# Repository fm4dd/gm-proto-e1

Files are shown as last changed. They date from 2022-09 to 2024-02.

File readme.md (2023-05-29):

## GM-PROTO-E1

### Description

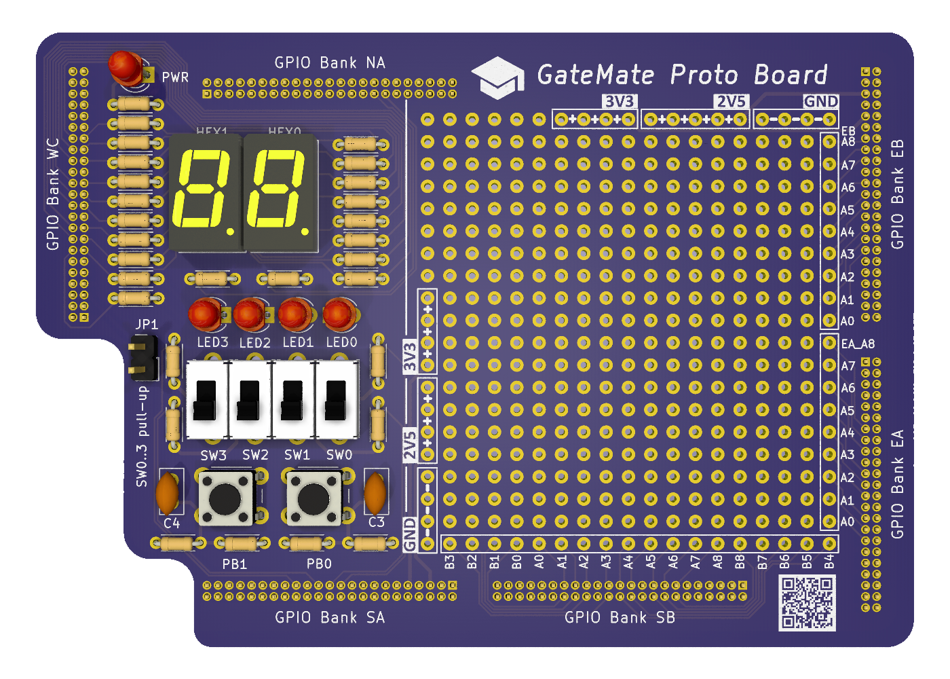
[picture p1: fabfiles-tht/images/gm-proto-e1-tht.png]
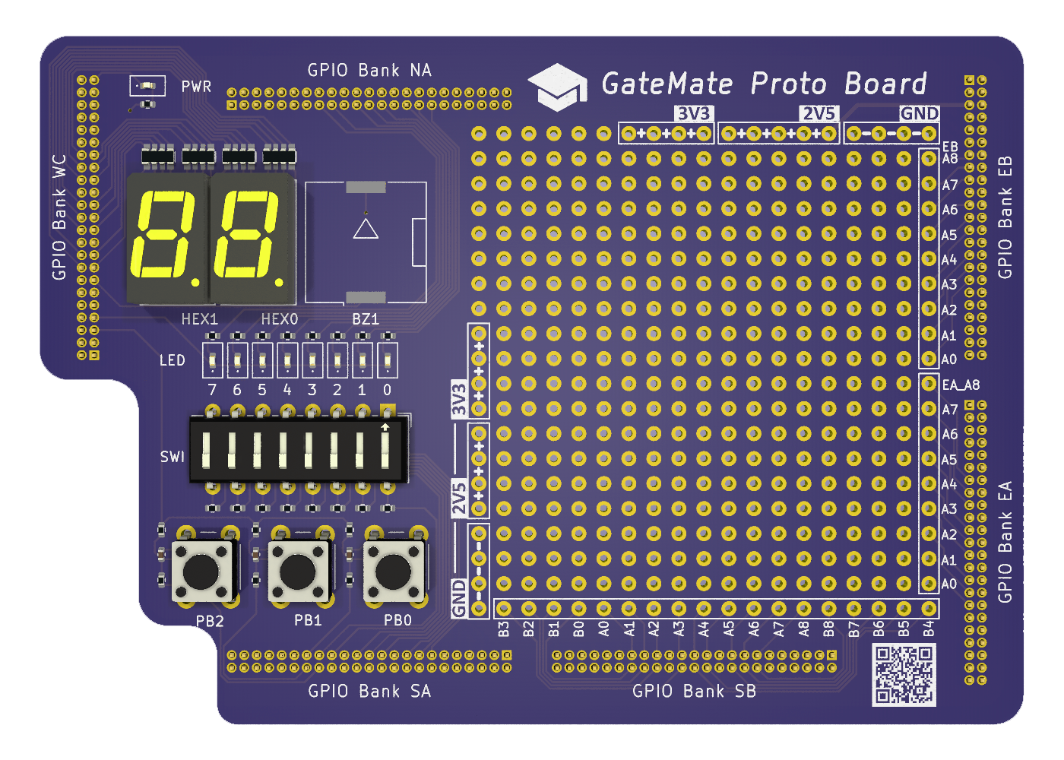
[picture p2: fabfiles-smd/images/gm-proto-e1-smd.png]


The gm-proto-e1 board is an application module board for the <a href="https://www.colognechip.com/programmable-logic/gatemate-evaluation-board/">GateMate FPGA evaluation board E1</a>, made by <a href="https://www.colognechip.com/">Cologne Chip</a>. It connects to the evaluation board through the GPIO bank headers, and its main feature is the 20x19 standard 2.54mm pitch prototyping area. 36 FPGA signals from GPIO banks SB, EA and EB are brought in to enable easy experimentation for connecting FPGA board peripherals. In addition, the application board provides a minimal set of data input/output components for basic FPGA interactions. Two variants have been designed: One for through-hole components, one for higher density SMD parts:

- 2x push buttons THT / 3x push buttons SMD
- 4x slide switches THT / 8x DIP switches SMD
- 4x LED THT / 8x LED SMD
- 2x 7-Segment display modules
- Buzzer (SMD only)

This design is registered under the OSHWA Open Source Hardware Self-Certification:  


### Hardware Versions

The gm-proto-e1 application board has been designed as a 100x70mm double-layer PCB, with precision alignment of the six 46-pin 1.27mm pitch GPIO connectors, verified to fit the GateMate FPGA evaluation board E1 V3.1B. For THT components, great care needs to be taken to cut pins flush during soldering and prevent them from reaching components of the evaluation board below. The 1.27mm pitch GPIO connectors are offered with different distance spacers (2, 2.5 and 5mm), and the standard spacers achieve only 5mm total clearance.

#### Through-hole Design:

| Version | Gerber | Schema |
|---|---|---|
| 1.0 |[20220914-gm-proto-e1-gerber.zip](fabfiles-tht/v10/20220914-gm-proto-e1-gerber.zip) | [20220914-gm-proto-e1-schematic.pdf](fabfiles-tht/v10/20220914-gm-proto-e1-schematic.pdf) |

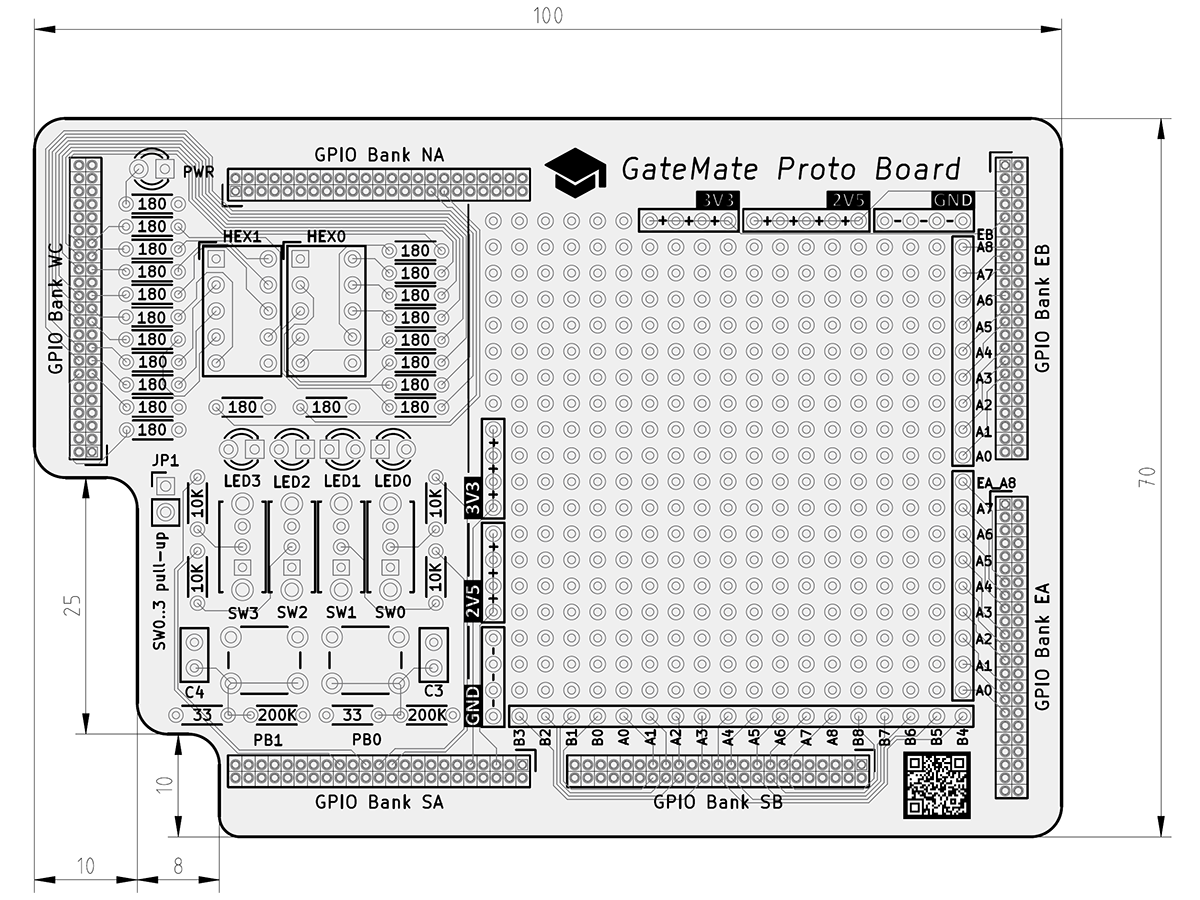
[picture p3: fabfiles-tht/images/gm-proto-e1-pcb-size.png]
 
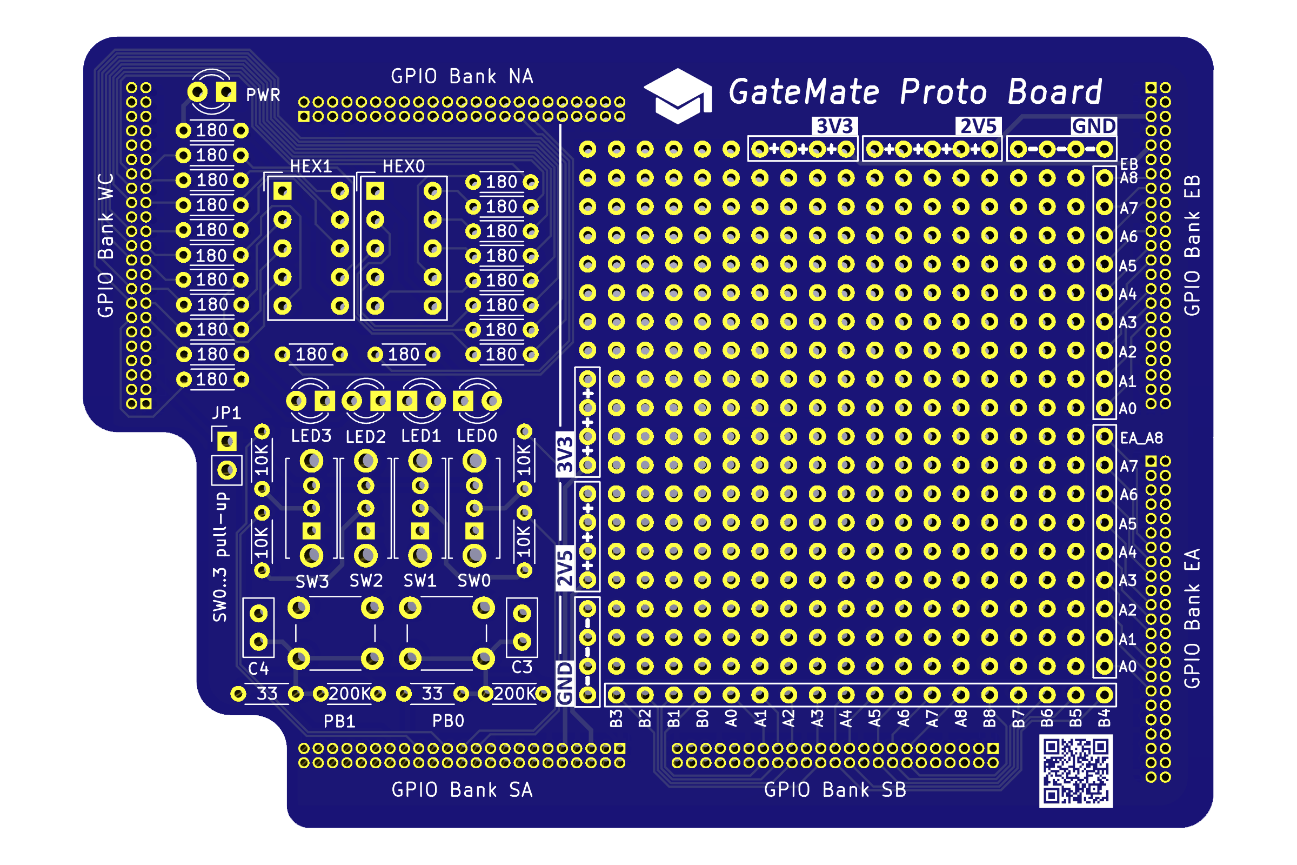
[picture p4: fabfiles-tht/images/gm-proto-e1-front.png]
 

#### Surface-Mount Design:

| Version | Gerber | Schema |
|---|---|---|
| 1.0 |[20220923-gm-proto-e1-gerber.zip](fabfiles-smd/v10/20220923-gm-proto-e1-gerber.zip) | [20220923-gm-proto-e1-schematic.pdf](fabfiles-smd/v10/20220923-gm-proto-e1-schematic.pdf) |

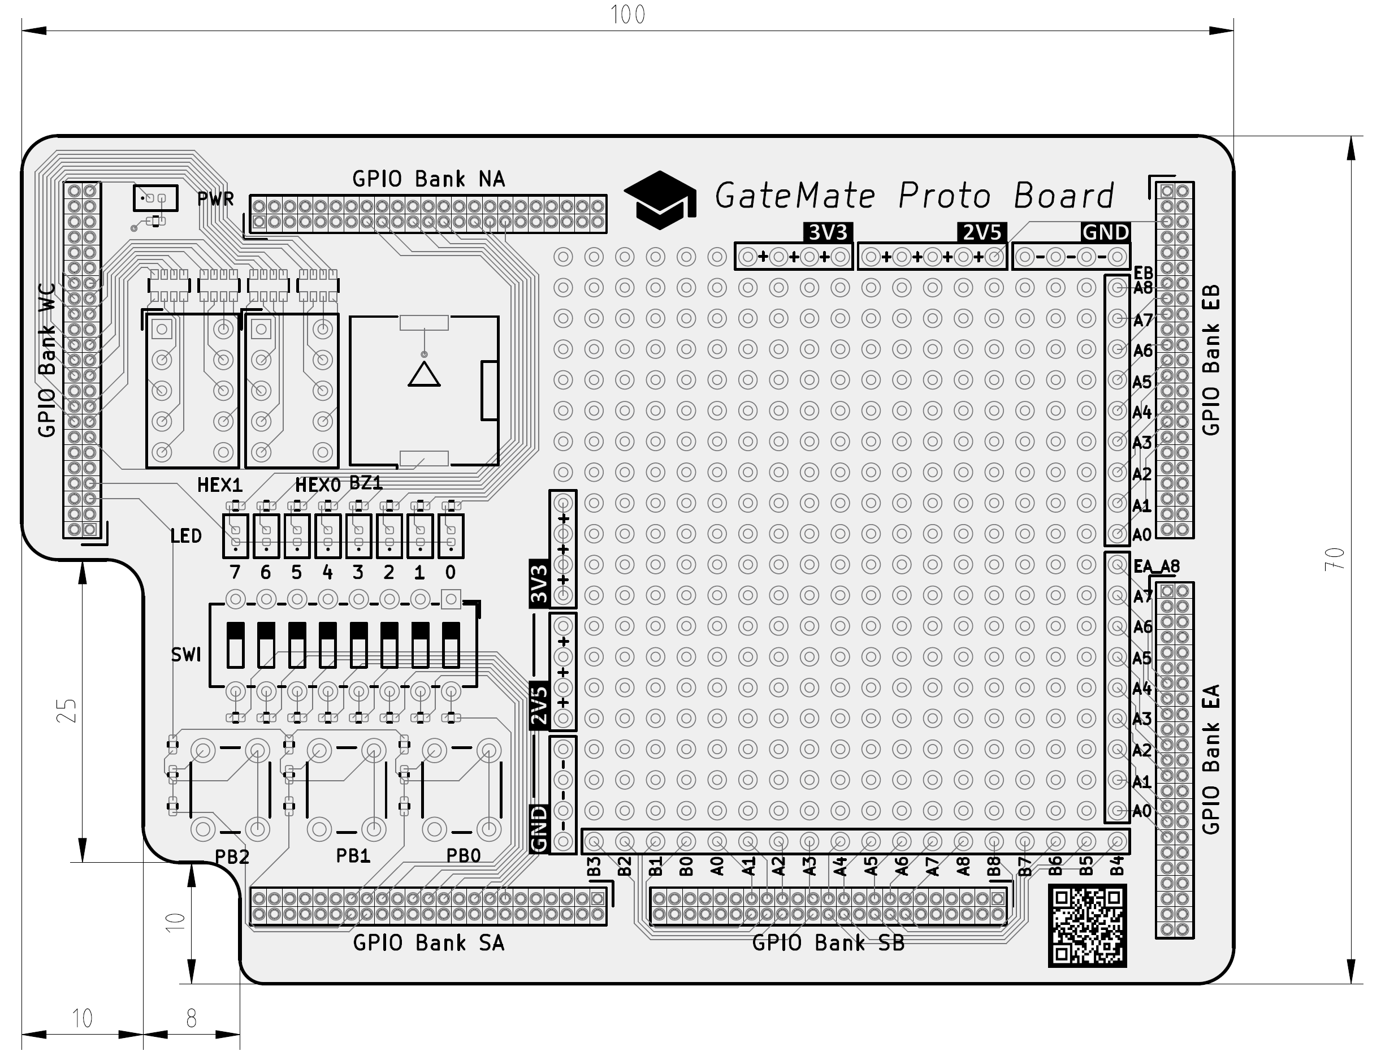
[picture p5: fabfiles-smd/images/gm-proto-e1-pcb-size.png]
 
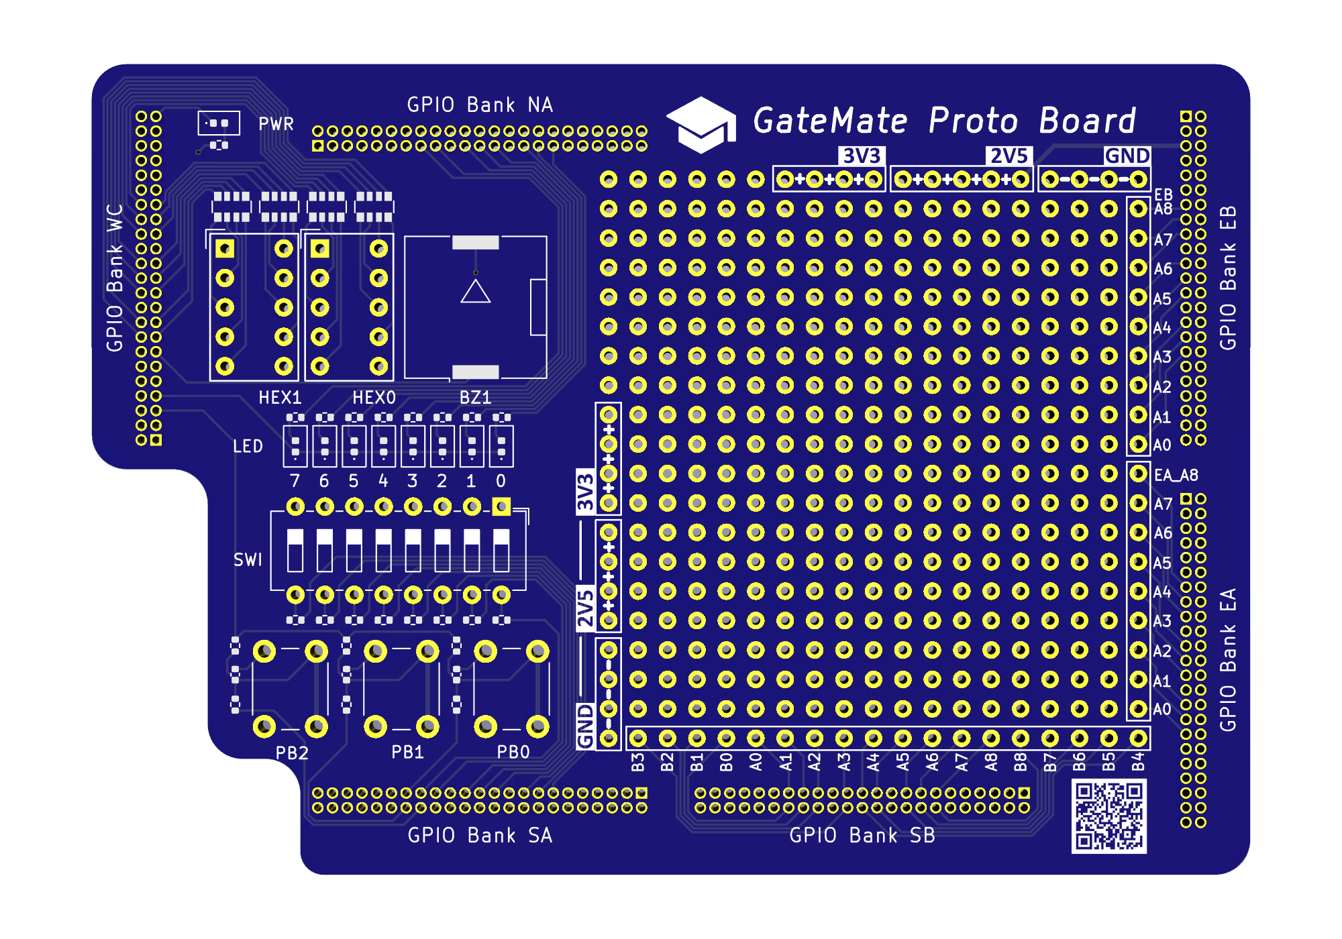
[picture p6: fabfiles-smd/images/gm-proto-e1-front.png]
 

### Pin Assignments

Due to IO differences between THT and SMD board variants, they have different pinouts:

#### Through-hole Design:

- IO pinout assigments file: [pin-assignment-tht.md](pin-assignment-tht.md)
- hardware constraints file: [gm-proto-e1-tht.ccf](examples-tht/gm-proto-e1-tht.ccf)

#### Surface-Mount Design:

- IO pinout assigments file: [pin-assignment-smd.md](pin-assignment-smd.md)
- hardware constraints file: [gm-proto-e1-smd.ccf](examples-smd/gm-proto-e10-smd.ccf)

Note: Components are prefixed with "pr", to identify them belonging to the gm-proto-e1 application board. For prototyping, 36 IO signals from GPIO banks SB, EA and EB have been placed into the 2.54mm area border pin rows.

### Example Code

The following code examples demonstrate the board input/output components for quick verification. The code has been tested with the pre-compiled opensource toolchain released through the GateMate support site at <a href="https://www.colognechip.com/mygatemate/">https://www.colognechip.com/mygatemate/</a>

#### Through-hole Design:

| Language | Folder | Description |
|---|---|---|
| Verilog  |[blink](examples-tht/blink) | blinks two LED's in a alternating pattern |
| Verilog  |[count](examples-tht/count) | binary counter displayed on four LED and two 7-Segment digits |
| Verilog  |[button](examples-tht/button) | push button press changes LED frequency and light move direction  |
| Verilog  |[switch](examples-tht/switch) | each slide switch turns its corresponding LED on or off |
| Verilog  |[display](examples-tht/display)| basic control of a HD44780-compatible 3.3V character LCD display  |
| Verilog  |[rotenc16](examples-tht/rotenc16)| basic control of a 16-position rotary encoder input switch  |

#### Surface-Mount Design:

| Language | Folder | Description |
|---|---|---|
| Verilog  |[blink](examples-smd/blink) | blinks four LED's in a alternating pattern |
| Verilog  |[count](examples-smd/count) | binary counter displayed on eight LED and two 7-Segment digits |
| Verilog  |[button](examples-smd/button)  | push button press changes LED frequency and light move direction  |
| Verilog  |[switch](examples-smd/switch)  | each slide switch turns its corresponding LED on or off |

### Board Pictures

The gm-proto-e1 THT board, before and after assembly.

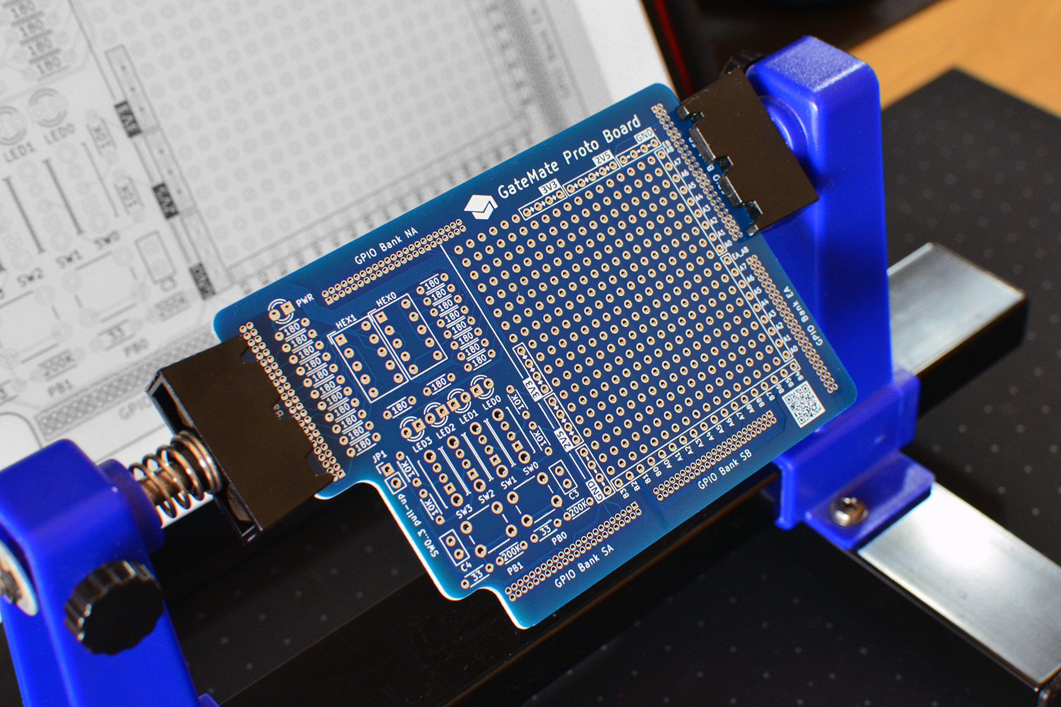
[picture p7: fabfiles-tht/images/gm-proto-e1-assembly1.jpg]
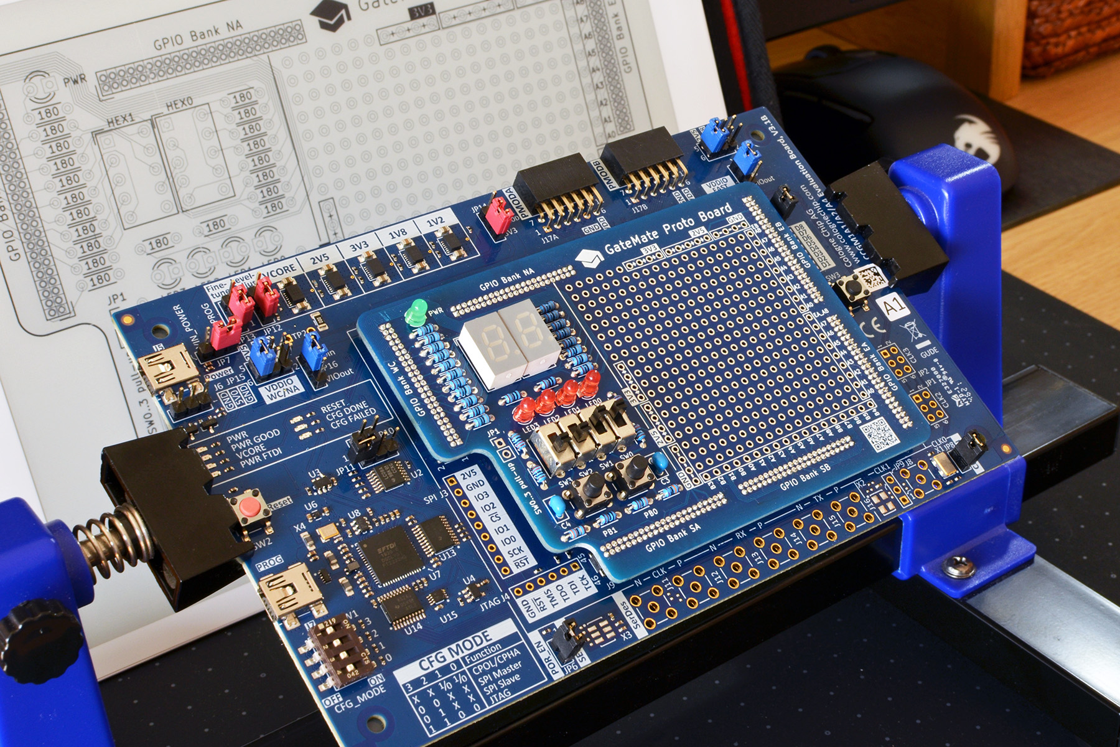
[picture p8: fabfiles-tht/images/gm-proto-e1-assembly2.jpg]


The gm-proto-e1 THT board has been designed with KiCad version 6.0.
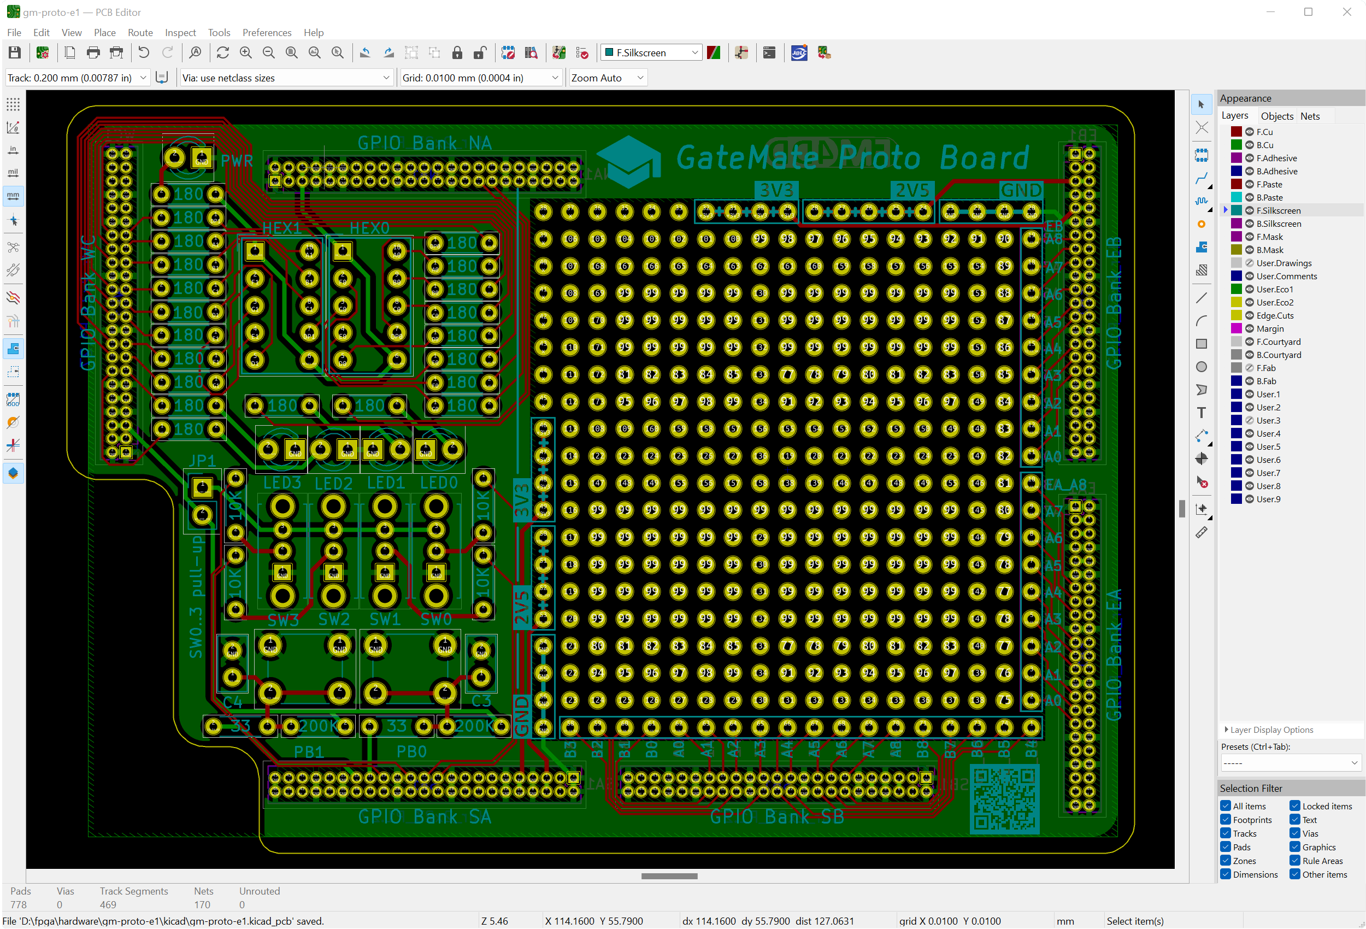
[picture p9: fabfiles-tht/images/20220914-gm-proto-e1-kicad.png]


The gm-proto-e1 THT board mounted on the E1 board, running the "count" demo.
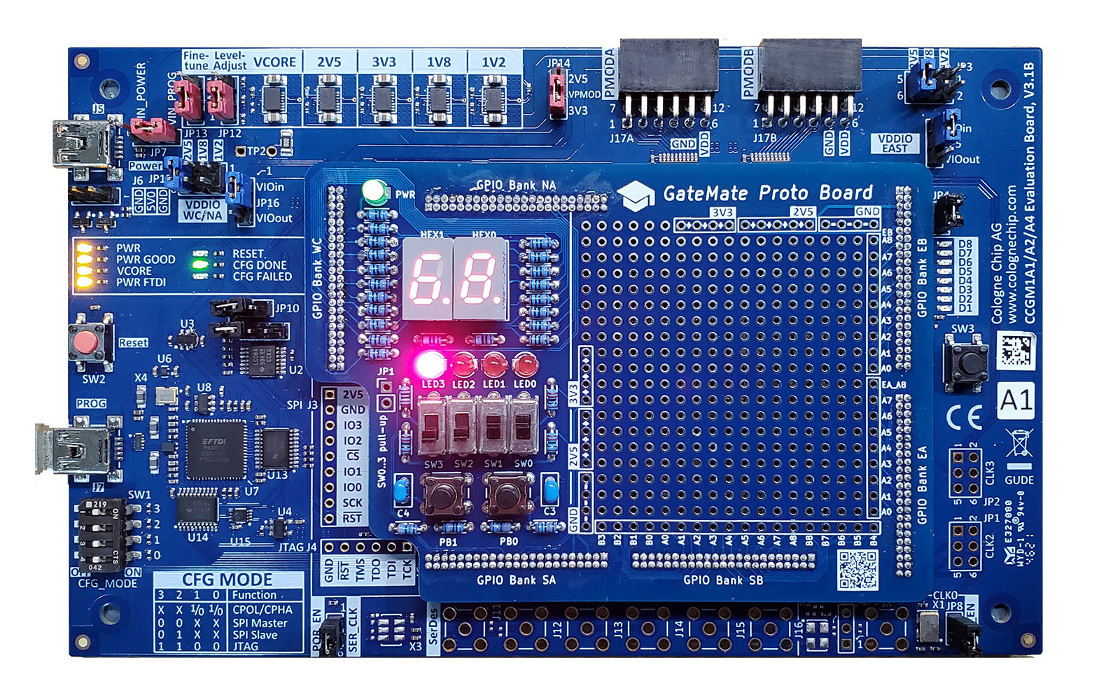
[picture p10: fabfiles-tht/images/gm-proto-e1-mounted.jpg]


The gm-proto-e1 THT board hardware verification video.
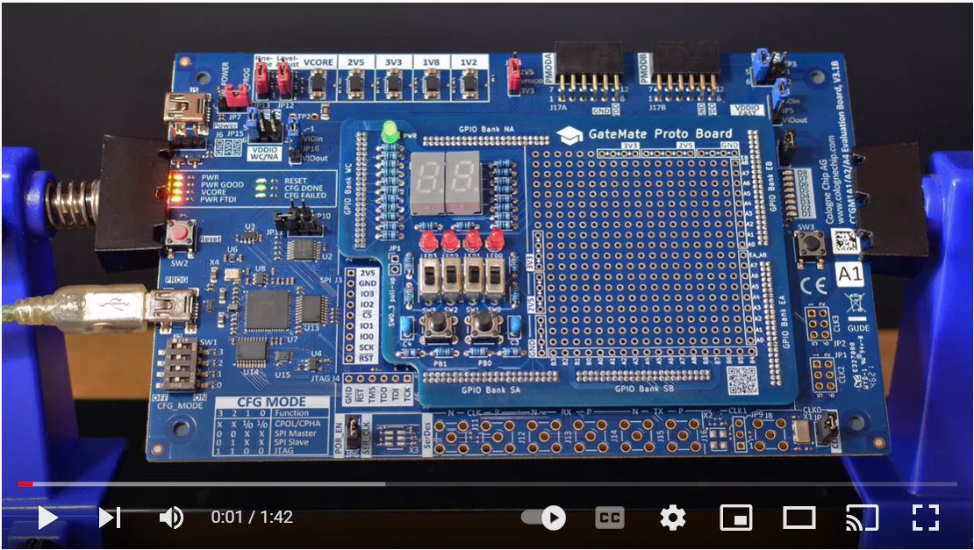
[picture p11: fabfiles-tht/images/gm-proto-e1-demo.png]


The gm-proto-e1 THT board, running the "display" demo
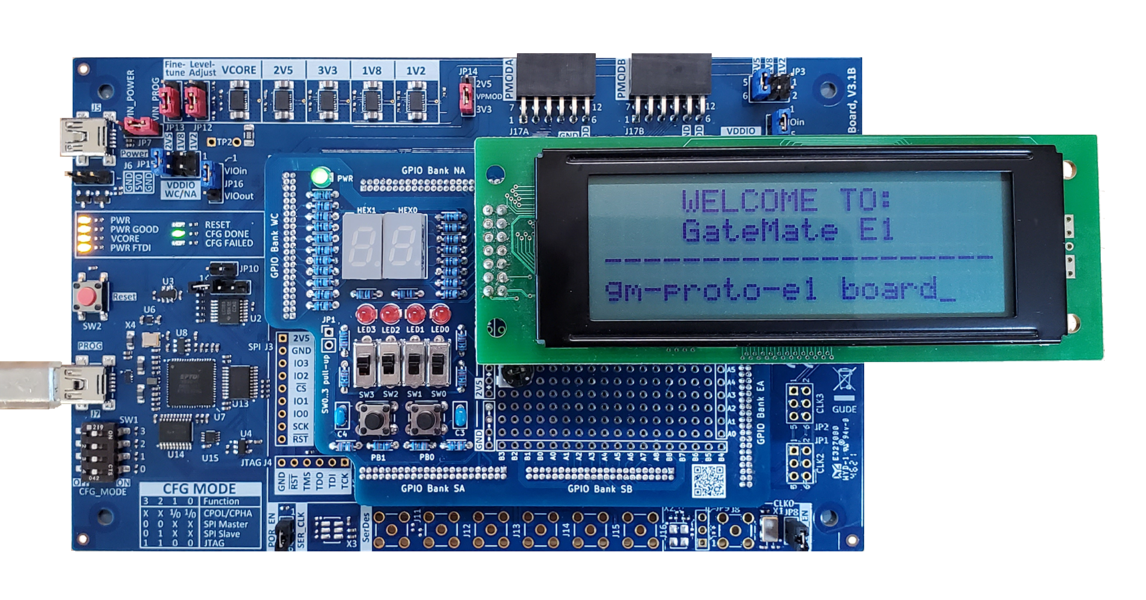
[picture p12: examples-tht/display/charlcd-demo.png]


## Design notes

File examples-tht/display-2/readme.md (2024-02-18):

## Gatemate E1 Character LCD Example "display-2"

This Verilog example program validates the function of an HD44780-compatible character LCD display in 8-bit mode. I am using a 3.3V display model Sunlike SC2004CSLB-XA-LB-G(4x20 chars). The FPGA 2.5V logic level is directly connected to the LCD IO lines via the 2x7 pin socket soldered to the GM-PROTO-E1 interface board from https://github.com/fm4dd/gm-proto-e1

The LCD interface is wired to the FPGA IO banks EB and EA per below schematic:
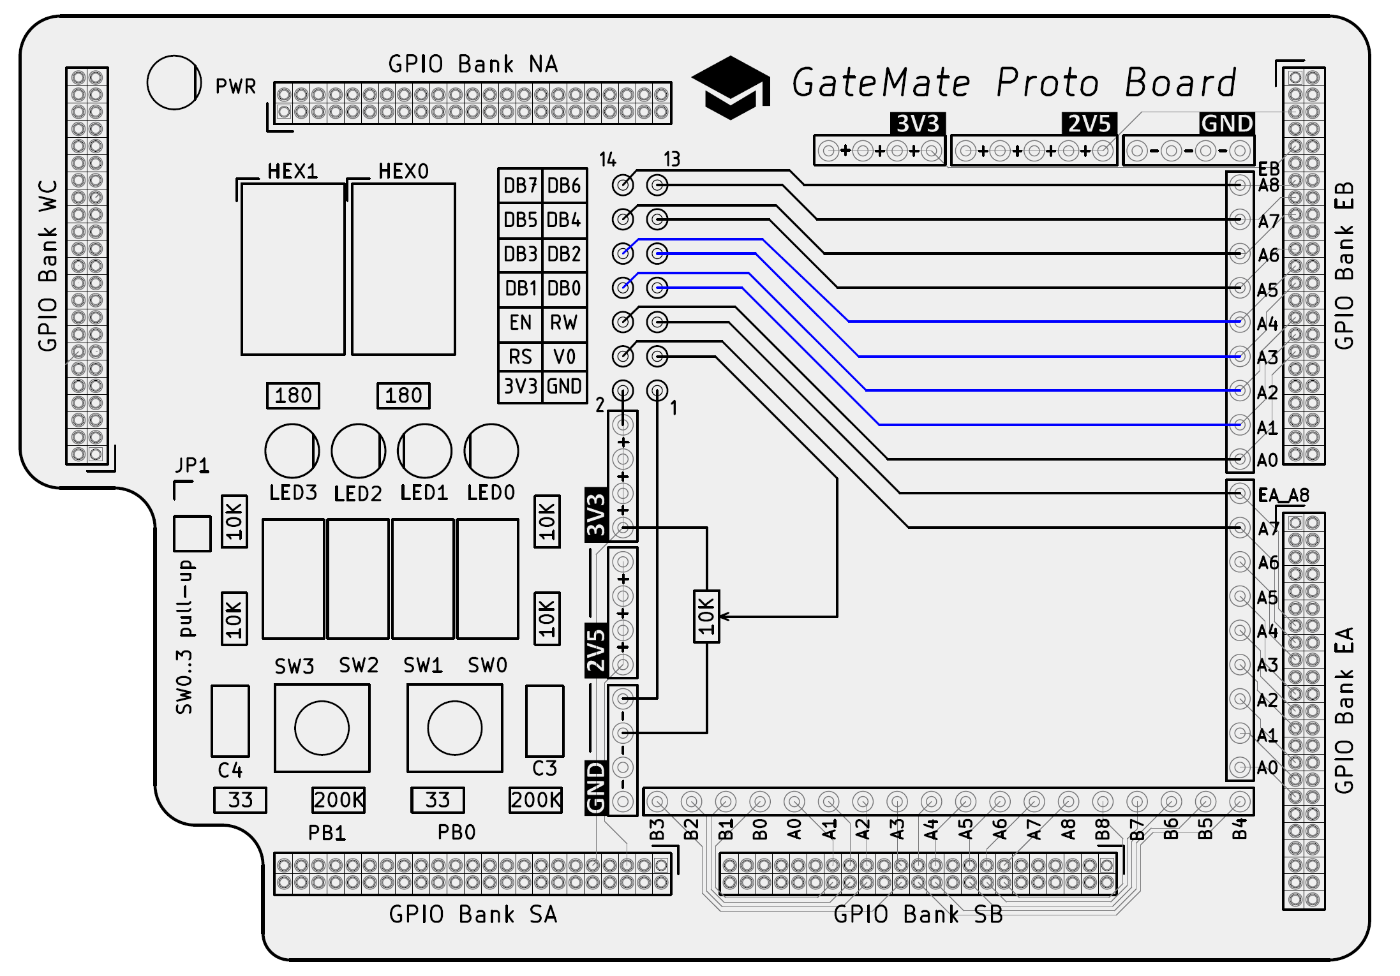
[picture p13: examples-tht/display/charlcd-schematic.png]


The hardware definition file for this setup is in [src/gm-proto-e1.ccf](src/gm-proto-e1.ccf)

The GM-PROTO-E1 pushbutton PB0 is used to toggle the display message on, and off (CLS). The LCD control line status is shown on the E1 onboard LEDs D1..D6, while the GM-PROTO-E1 LED0 and LED1 show the PB0 toggle state.

### Usage

```
fm@nuc7fpga:/mnt/hgfs/fpga/hardware/gm-proto-e1/examples-tht/display-2$ make all
/home/fm/cc-toolchain-linux/bin/yosys/yosys -ql log/synth.log -p 'read -sv src/debounce.v src/display.v src/lcd_transmit.v; synth_gatemate -top display -nomx8 -vlog net/display_synth.v'
/home/fm/cc-toolchain-linux/bin/p_r/p_r -i net/display_synth.v -o display -ccf src/gm-proto-e1.ccf > log/impl.log
/usr/bin/openFPGALoader  -b gatemate_evb_jtag display_00.cfg
Jtag frequency : requested 6.00MHz   -> real 6.00MHz  
Load SRAM via JTAG: [==================================================] 100.00%
Done
Wait for CFG_DONE DONE
```

The example will look like this:
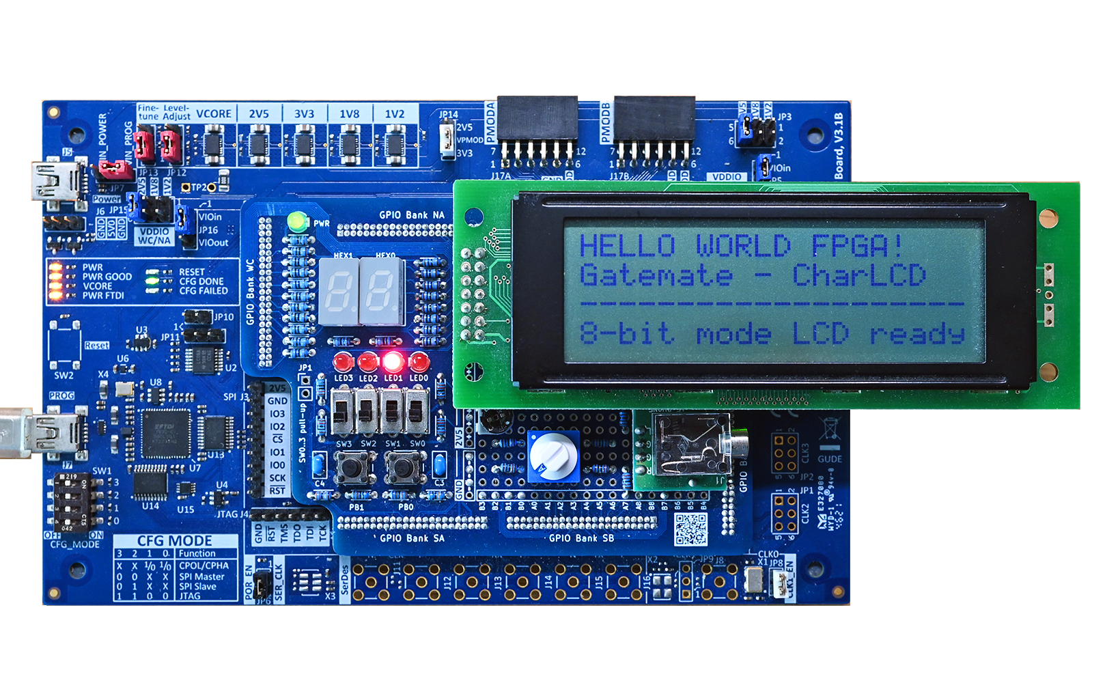
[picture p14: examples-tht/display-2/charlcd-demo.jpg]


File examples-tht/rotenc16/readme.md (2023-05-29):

## GM-PROTO-E1 Example "rotenc16"



This Verilog example program validates the function of a single 16-position rotary encoder, soldered into the prototyping area of the GM-Proto-E1 board. I am using model ERD216RSZ from vendor Excel Cell Electronics (ECE). 16-position rotary encoders are convenient as data input. With two encoders it is possble to quickly set the hex value of one byte.

### Schematic

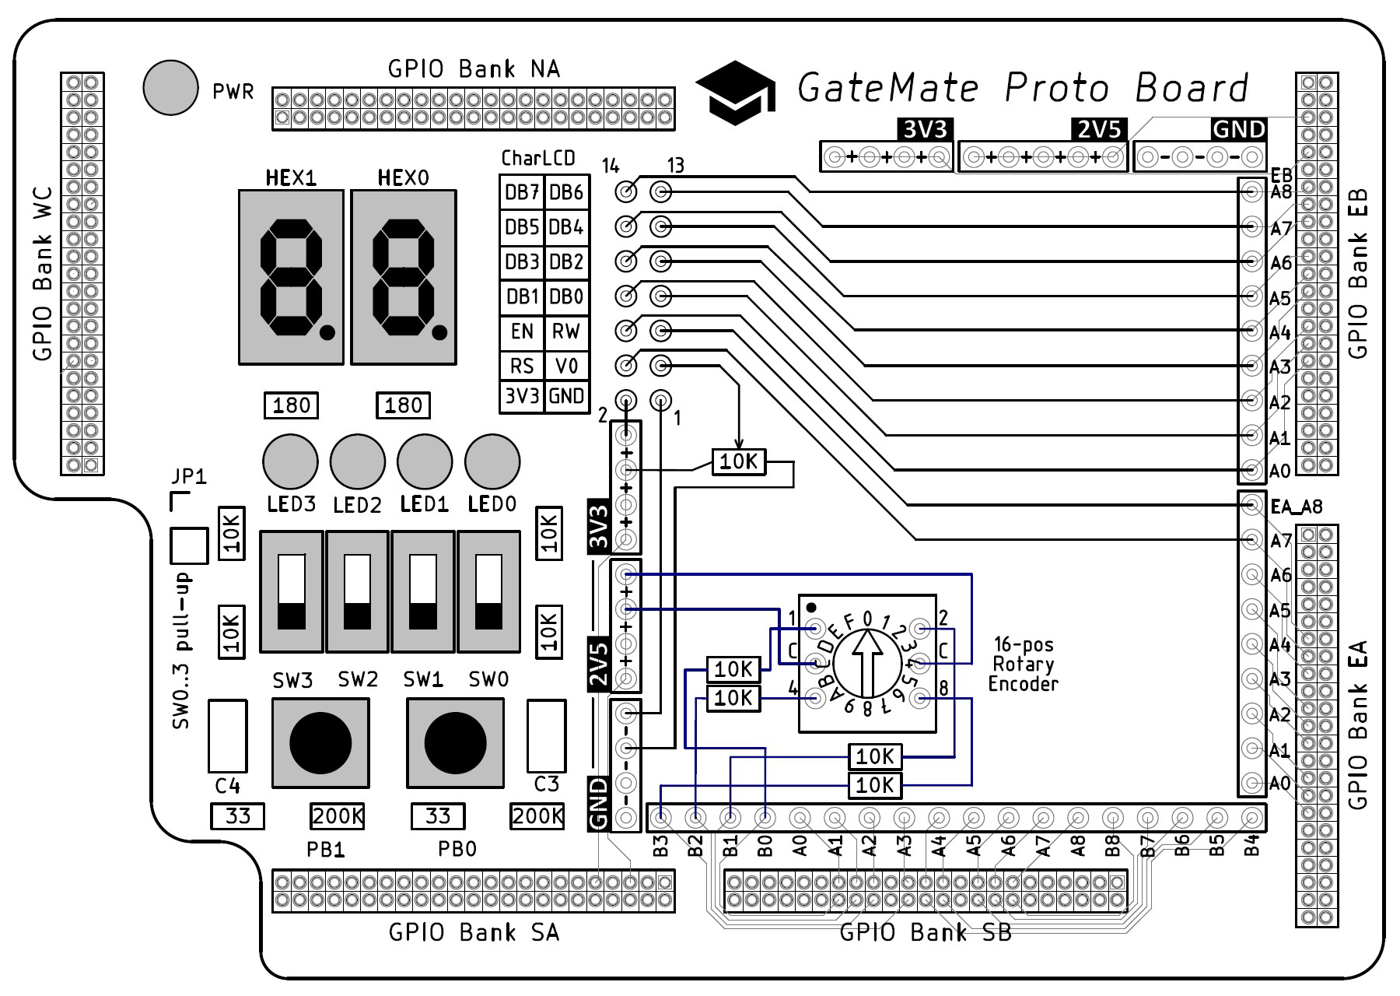
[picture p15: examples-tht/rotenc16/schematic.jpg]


### Verilog Code

Verilog code is likewise very simple. The encoder input signal pins can be assigned directly as bit values of one nibble (half-byte). On the GM-Proto-E1 board, we can map the encoder signal bit range straight to the 4 output LED's, and to one of the 7-segment LED displays to show the value in hex.

```
// -------------------------------------------------------
// rotenc16.v   gm-proto-e1 demo program   @20230528 fm4dd
//
// Requires: 4x LEDs, 16-pos rotary encoder, 1x 7-Seg LED
//
// Description:
// ------------
// This program shows the rotary encoder signal on LED0-3,
// and the corresponding hex code on 7-seg display prhex0.
// -------------------------------------------------------
module rotenc16(
  input wire [3:0] prrot,
  output wire [3:0] prled,
  output [7:0] prhex0
);

// -------------------------------------------------------
//  Module hexdigit: Creates the LED pattern from 3 args:
// in:  0-16 sets hex value of led segments, >16 is extra
// dp:  0 or 1, disables/enables the decimal point led
// out: this is the bit pattern for the 7seg module led's
//
// Note: Because 'in' is 5-bit wide to display extra chars
// we set the unused highest bit in[4] to 0, and assign
// the prrot signal to the remaining bits at in[3:0].
// -------------------------------------------------------
  hexdigit h0 ({1'b0, prrot}, 1'b0, prhex0);
  assign prled = prrot;
endmodule
```

### Pin assignment

added in src/gm-proto-e1.ccf:
```
## #######################################################
## gm-proto-e1 proto area 16-pos rotary encoder connection
## #######################################################
Pin_in "prrot[0]"    Loc = "IO_SB_B0" | PULLDOWN=true;
Pin_in "prrot[1]"    Loc = "IO_SB_B1" | PULLDOWN=true;
Pin_in "prrot[2]"    Loc = "IO_SB_B2" | PULLDOWN=true;
Pin_in "prrot[3]"    Loc = "IO_SB_B3" | PULLDOWN=true;

```

### Usage

```
fm@nuc7vm2204:~/fpga/hardware/gm-proto-e1/examples-tht/rotenc16$ make all
/home/fm/cc-toolchain-linux/bin/yosys/yosys -ql log/synth.log -p 'read -sv src/hexdigit.v src/rotenc16.v; synth_gatemate -top rotenc16 -nomx8 -vlog net/rotenc16_synth.v'
/home/fm/cc-toolchain-linux/bin/p_r/p_r -i net/rotenc16_synth.v -o rotenc16 -ccf src/gm-proto-e1-tht.ccf > log/impl.log
/usr/local/bin/openFPGALoader  -b gatemate_evb_jtag rotenc16_00.cfg
Jtag frequency : requested 6.00MHz   -> real 6.00MHz  
Load SRAM via JTAG: [==================================================] 100.00%
Done
Wait for CFG_DONE DONE
```

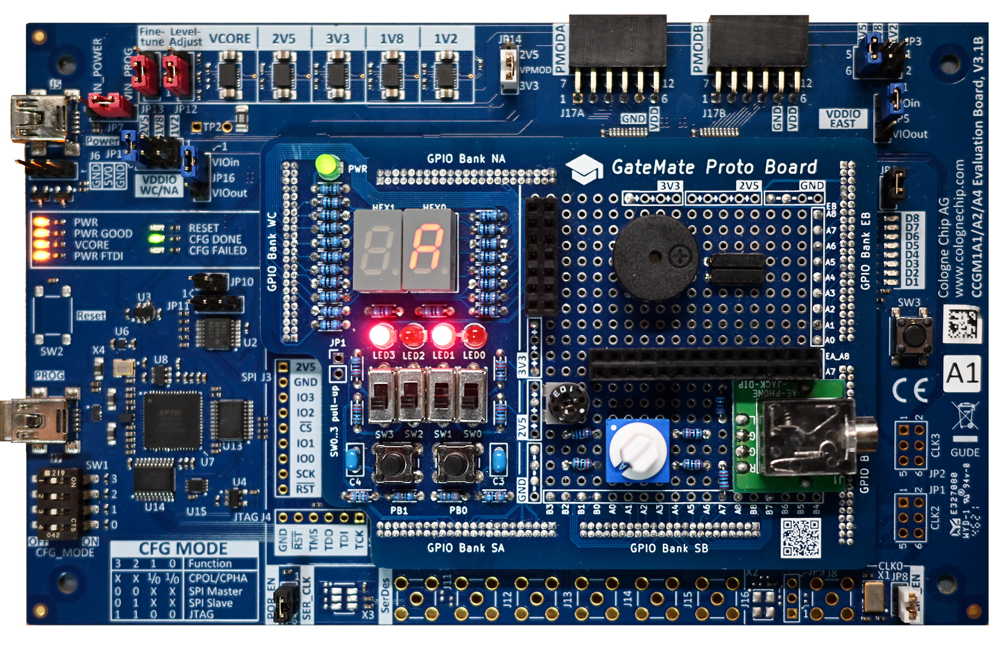
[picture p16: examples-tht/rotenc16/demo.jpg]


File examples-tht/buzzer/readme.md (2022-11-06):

## GM-PROTO-E1 Example "buzzer"

This Verilog example program validates the function of a buzzer sound module soldered into the prototyping area. The example has the buzzer + signal connected as "prbuz" to IO_EA_A6. A press on each of the two push buttons creates a different frequency, which outputs a different tone on the buzzer. Each button lights up its equivalent LED, and the button number is displayed on two of the six 7-segment display modules as b0 or b1.

### Usage

```
fm@nuc7vm2204:~/fpga/hardware/gm-proto-e1/examples-tht/buzzer$ make all
/home/fm/cc-toolchain-linux/bin/yosys/yosys -ql log/synth.log -p 'read -sv src/buzzer.v src/hexdigit.v; synth_gatemate -top buzzer -nomx8 -vlog net/buzzer_synth.v'
/home/fm/cc-toolchain-linux/bin/p_r/p_r -i net/buzzer_synth.v -o buzzer -ccf ../gm-proto-e1-tht.ccf > log/impl.log
/usr/local/bin/openFPGALoader  -b gatemate_evb_jtag buzzer_00.cfg
Jtag frequency : requested 6.00MHz   -> real 6.00MHz  
Load SRAM via JTAG: [==================================================] 100.00%
Done
Wait for CFG_DONE DONE
```

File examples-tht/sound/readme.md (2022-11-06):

## GM-PROTO-E1 Example "sound"

This Verilog example program validates the function of a buzzer sound module soldered into the prototyping area by playing a melody. The example has the buzzer + signal connected as "prbuz" to IO_EA_A6.
A press of push button PB0 starts or stops the song. The note values are displayed as binary on the LEDs, and with their value on the two 7-Segment digits. The song played is "Rudolf the rednosed reindeer", with the source code adapted from https://www.fpga4fun.com/MusicBox4.html.

### Usage

```
fm@nuc7vm2204:~/fpga/hardware/gm-proto-e1/examples-tht/sound$ make all
/home/fm/cc-toolchain-linux/bin/yosys/yosys -ql log/synth.log -p 'read -sv src/debounce.v src/hexdigit.v src/sound.v; synth_gatemate -top sound -nomx8 -vlog net/sound_synth.v'
/home/fm/cc-toolchain-linux/bin/p_r/p_r -i net/sound_synth.v -o sound -ccf src/gm-proto-e1-tht.ccf > log/impl.log
/usr/local/bin/openFPGALoader  -b gatemate_evb_jtag sound_00.cfg
Jtag frequency : requested 6.00MHz   -> real 6.00MHz  
Load SRAM via JTAG: [==================================================] 100.00%
Done
Wait for CFG_DONE DONE
```

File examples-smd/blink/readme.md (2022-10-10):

## GM-PROTO-E1 Example "blink"

This Verilog example program validates the function of the four LED0..3. Using a clock divider for the 10MHz system clock, it alternates between even and odd LEDs with a frequency of 2Hz.

### Usage

```
fm@nuc7vm2204:~/fpga/hardware/gm-proto-e1/examples-smd/blink$ make all
/home/fm/cc-toolchain-linux/bin/yosys/yosys -ql log/synth.log -p 'read -sv src/blink.v; synth_gatemate -top blink -vlog net/blink_synth.v'
/home/fm/cc-toolchain-linux/bin/p_r/p_r -i net/blink_synth.v -o blink -ccf ../gm-proto-e1-smd.ccf > log/impl.log
/usr/local/bin/openFPGALoader  -b gatemate_evb_jtag blink_00.cfg
Jtag frequency : requested 6.00MHz   -> real 6.00MHz  
Load SRAM via JTAG: [==================================================] 100.00%
Done
Wait for CFG_DONE DONE
```

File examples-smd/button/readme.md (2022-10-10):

## GM-PROTO-E1 Example "button"

This Verilog example program validates the function of the two push buttons PB0 and PB1. Push buttons are a bit tricky for the need of clock synchronisation and debounce. In this program, a running light moves over the eight LEDs. Push button PB0 controls the speed in 4 levels (1,2,4,8Hz), while push button PB1 controls the direction of the movement. The current state is displayed on the two 7-Segment modules: HEX0 displays the speed level 0..3, and HEX1 shows the direction F (forward) or b (backward).

### Usage

```
fm@nuc7vm2204:~/fpga/hardware/gm-proto-e1/examples-smd/button$ make all
/home/fm/cc-toolchain-linux/bin/yosys/yosys -ql log/synth.log -p 'read -sv src/button.v src/debounce.v src/hexdigit.v; synth_gatemate -top button -vlog net/button_synth.v'
/home/fm/cc-toolchain-linux/bin/p_r/p_r -i net/button_synth.v -o button -ccf ../gm-proto-e1-smd.ccf > log/impl.log
/usr/local/bin/openFPGALoader  -b gatemate_evb_jtag button_00.cfg
Jtag frequency : requested 6.00MHz   -> real 6.00MHz  
Load SRAM via JTAG: [==================================================] 100.00%
Done
Wait for CFG_DONE DONE
```

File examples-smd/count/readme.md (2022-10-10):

## GM-PROTO-E1 Example "count"

This Verilog example program is a binary counter, displayed in binary on the LED's, and in hexadecimal on the two 7-Segment digits.  The hex digits can be enabled or disabled by slide switches SW0 and SW1. The counter runs at 1Hz, and the 7-segment decimal points pulse the counter clock. The counter clock is derived from the 10MHz system clock of the evaluation board.

### Usage

```
fm@nuc7vm2204:~/fpga/hardware/gm-proto-e1/examples-smd/count$ make all
/home/fm/cc-toolchain-linux/bin/yosys/yosys -ql log/synth.log -p 'read -sv src/count.v src/hexdigit.v; synth_gatemate -top count -vlog net/count_synth.v'
/home/fm/cc-toolchain-linux/bin/p_r/p_r -i net/count_synth.v -o count -ccf ../gm-proto-e1-smd.ccf > log/impl.log
/usr/local/bin/openFPGALoader  -b gatemate_evb_jtag count_00.cfg
Jtag frequency : requested 6.00MHz   -> real 6.00MHz  
Load SRAM via JTAG: [==================================================] 100.00%
Done
Wait for CFG_DONE DONE
```

Running "count" example on the gm-proto-e1 module


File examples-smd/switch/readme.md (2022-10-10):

## GM-PROTO-E1 Example "switch"

This Verilog example program validates the function of the eight DIP switches. This program works without a clock. Turning a slide switch "on" enables the respective board LED0..7. If only a single switch is on, and remaining switches are "off", the switch number gets shown on the 7-segment display modules as S0..S7, or as SA if all switches are on.

### Usage

```
fm@nuc7vm2204:~/fpga/hardware/gm-proto-e1/examples-smd/switch$ make all
/home/fm/cc-toolchain-linux/bin/yosys/yosys -ql log/synth.log -p 'read -sv src/hexdigit.v src/switch.v; synth_gatemate -top switch -vlog net/switch_synth.v'
/home/fm/cc-toolchain-linux/bin/p_r/p_r -i net/switch_synth.v -o switch -ccf ../gm-proto-e1-smd.ccf > log/impl.log
/usr/local/bin/openFPGALoader  -b gatemate_evb_jtag switch_00.cfg
Jtag frequency : requested 6.00MHz   -> real 6.00MHz  
Load SRAM via JTAG: [==================================================] 100.00%
Done
Wait for CFG_DONE DONE
```

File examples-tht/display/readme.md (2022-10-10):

## GM-PROTO-E1 Example "display"

This Verilog example program validates the function of an HD44780-compatible character LCD display.
The display connects to a 7x2 pin socket, wired on the prototype area with following schematic:



I am using a 3.3V display model Sunlike SC2004CSLB-XA-LB-G(4x20 chars).
The 2.5V logic level is directly connected to the LCD IO lines.

**Note:**
The Verilog code operates the display in 4-bit mode, which leaves wires DB0..3 (blue color) unused.
In this demo, the hardware constraints file is located inside the "src" folder.

### Usage

```
fm@nuc7vm2204:~/fpga/hardware/gm-proto-e1/examples-tht/display$ make all
/home/fm/cc-toolchain-linux/bin/yosys/yosys -ql log/synth.log -p 'read -sv src/display.v; synth_gatemate -top display -vlog net/display_synth.v'
/home/fm/cc-toolchain-linux/bin/p_r/p_r -i net/display_synth.v -o display -ccf src/gm-proto-e1-charlcd.ccf > log/impl.log
/usr/local/bin/openFPGALoader  -b gatemate_evb_jtag display_00.cfg
Jtag frequency : requested 6.00MHz   -> real 6.00MHz
Load SRAM via JTAG: [==================================================] 100.00%
Done
Wait for CFG_DONE DONE
```



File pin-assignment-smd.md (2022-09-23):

## gm-proto-e1 Pin Assignment for SMD board variant

Note: Components are prefixed with "pr", to identify them belonging to the gm-proto-e1 application board.

#### 8x LED output "prled" on IO Bank NA

Name     | Location | Direction | Standard | comment
---------|----------|-----------|----------|---------
prled[0] | IO_NA_A8 | output    | 2.5V     |
prled[1] | IO_NA_A7 | output    | 2.5V     |
prled[2] | IO_NA_A6 | output    | 2.5V     |
prled[3] | IO_NA_A5 | output    | 2.5V     |
prled[4] | IO_NA_A4 | output    | 2.5V     |
prled[5] | IO_NA_A3 | output    | 2.5V     |
prled[6] | IO_NA_A2 | output    | 2.5V     |
prled[7] | IO_NA_A1 | output    | 2.5V     |

#### 2x 7-Segment Digits "prhex0" and "prhex1"

Name      | Location | Direction | Standard | comment
----------|----------|-----------|----------|-----------
prhex0[0] | IO_WC_B1 | output    | 2.5V     | hex0 - DP
prhex0[1] | IO_WC_B2 | output    | 2.5V     | hex0 - A
prhex0[2] | IO_WC_B3 | output    | 2.5V     | hex0 - B
prhex0[3] | IO_WC_B4 | output    | 2.5V     | hex0 - C
prhex0[4] | IO_WC_B5 | output    | 2.5V     | hex0 - D
prhex0[5] | IO_WC_B6 | output    | 2.5V     | hex0 - E
prhex0[6] | IO_WC_B7 | output    | 2.5V     | hex0 - F
prhex0[7] | IO_WC_B8 | output    | 2.5V     | hex0 - G

Name      | Location | Direction | Standard | comment
----------|----------|-----------|----------|--------
prhex1[0] | IO_WC_A8 | output    | 2.5V     | hex1 - DP
prhex1[1] | IO_WC_A7 | output    | 2.5V     | hex1 - A
prhex1[2] | IO_WC_A6 | output    | 2.5V     | hex1 - B
prhex1[3] | IO_WC_A5 | output    | 2.5V     | hex1 - C
prhex1[4] | IO_WC_A4 | output    | 2.5V     | hex1 - D
prhex1[5] | IO_WC_A3 | output    | 2.5V     | hex1 - E
prhex1[6] | IO_WC_A2 | output    | 2.5V     | hex1 - F
prhex1[7] | IO_WC_A1 | output    | 2.5V     | hex1 - G

#### 4x DIP Switch input "prswi" on IO Bank SA

Name     | Location | Direction | Standard | comment
---------|----------|-----------|----------|--------
prswi[0] | IO_SA_A1 | input     | 2.5V     |
prswi[1] | IO_SA_A2 | input     | 2.5V     |
prswi[2] | IO_SA_A3 | input     | 2.5V     |
prswi[3] | IO_SA_A4 | input     | 2.5V     |
prswi[4] | IO_SA_A5 | input     | 2.5V     |
prswi[5] | IO_SA_A6 | input     | 2.5V     |
prswi[6] | IO_SA_A7 | input     | 2.5V     |
prswi[7] | IO_SA_A8 | input     | 2.5V     |

#### 3x Push Buttons "prbtn" on IO Bank SA

Name     | Location | Direction | Standard | comment
---------|----------|-----------|----------|--------
prbtn[0] | IO_SA_A0 | input     | 2.5V     |
prbtn[1] | IO_SA_B0 | input     | 2.5V     |
prbtn[2] | IO_SA_B1 | input     | 2.5V     |

### 1x Buzzer "prbuz" on IO Bank WC

Name     | Location | Direction | Standard | comment
---------|----------|-----------|----------|--------
prbuz    | IO_WC_A0 | input     | 2.5V     |

For prototyping, 36 IO signals from GPIO banks SB, EA and EB have been placed into the 2.54mm area border pin rows.

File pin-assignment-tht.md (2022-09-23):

## gm-proto-e1 Pin Assignment for THT board variant

Note: Components are prefixed with "pr", to identify them belonging to the gm-proto-e1 application board.

#### 4x LED output "prled" on IO Bank NA and WC

Name     | Location | Direction | Standard | comment
---------|----------|-----------|----------|---------
prled[0] | IO_NA_A7 | output    | 2.5V     |
prled[1] | IO_NA_A8 | output    | 2.5V     |
prled[2] | IO_WC_B0 | output    | 2.5V     |
prled[3] | IO_WC_A0 | output    | 2.5V     |

#### 2x 7-Segment Digits "prhex0" and "prhex1"

Name      | Location | Direction | Standard | comment
----------|----------|-----------|----------|-----------
prhex0[0] | IO_WC_B8 | output    | 2.5V     | hex0 - DP
prhex0[1] | IO_WC_B7 | output    | 2.5V     | hex0 - A
prhex0[2] | IO_WC_B6 | output    | 2.5V     | hex0 - B
prhex0[3] | IO_WC_B5 | output    | 2.5V     | hex0 - C
prhex0[4] | IO_WC_B4 | output    | 2.5V     | hex0 - D
prhex0[5] | IO_WC_B3 | output    | 2.5V     | hex0 - E
prhex0[6] | IO_WC_B2 | output    | 2.5V     | hex0 - F
prhex0[7] | IO_WC_B1 | output    | 2.5V     | hex0 - G

Name      | Location | Direction | Standard | comment
----------|----------|-----------|----------|--------
prhex1[0] | IO_WC_A8 | output    | 2.5V     | hex1 - DP
prhex1[1] | IO_WC_A7 | output    | 2.5V     | hex1 - A
prhex1[2] | IO_WC_A6 | output    | 2.5V     | hex1 - B
prhex1[3] | IO_WC_A5 | output    | 2.5V     | hex1 - C
prhex1[4] | IO_WC_A4 | output    | 2.5V     | hex1 - D
prhex1[5] | IO_WC_A3 | output    | 2.5V     | hex1 - E
prhex1[6] | IO_WC_A2 | output    | 2.5V     | hex1 - F
prhex1[7] | IO_WC_A1 | output    | 2.5V     | hex1 - G

#### 4x Slide Switch input "prswi" on IO Bank SA

Name     | Location | Direction | Standard | comment
---------|----------|-----------|----------|--------
prswi[0] | IO_SA_A5 | input     | 2.5V     |
prswi[1] | IO_SA_A4 | input     | 2.5V     |
prswi[2] | IO_SA_A3 | input     | 2.5V     |
prswi[3] | IO_SA_A2 | input     | 2.5V     |

#### 2x Push Buttons "prbtn" on IO Bank SA

Name     | Location | Direction | Standard | comment
---------|----------|-----------|----------|--------
prbtn[0] | IO_SA_A1 | input     | 2.5V     |
prbtn[1] | IO_SA_A0 | input     | 2.5V     |

For prototyping, 36 IO signals from GPIO banks SB, EA and EB have been placed into the 2.54mm area border pin rows.

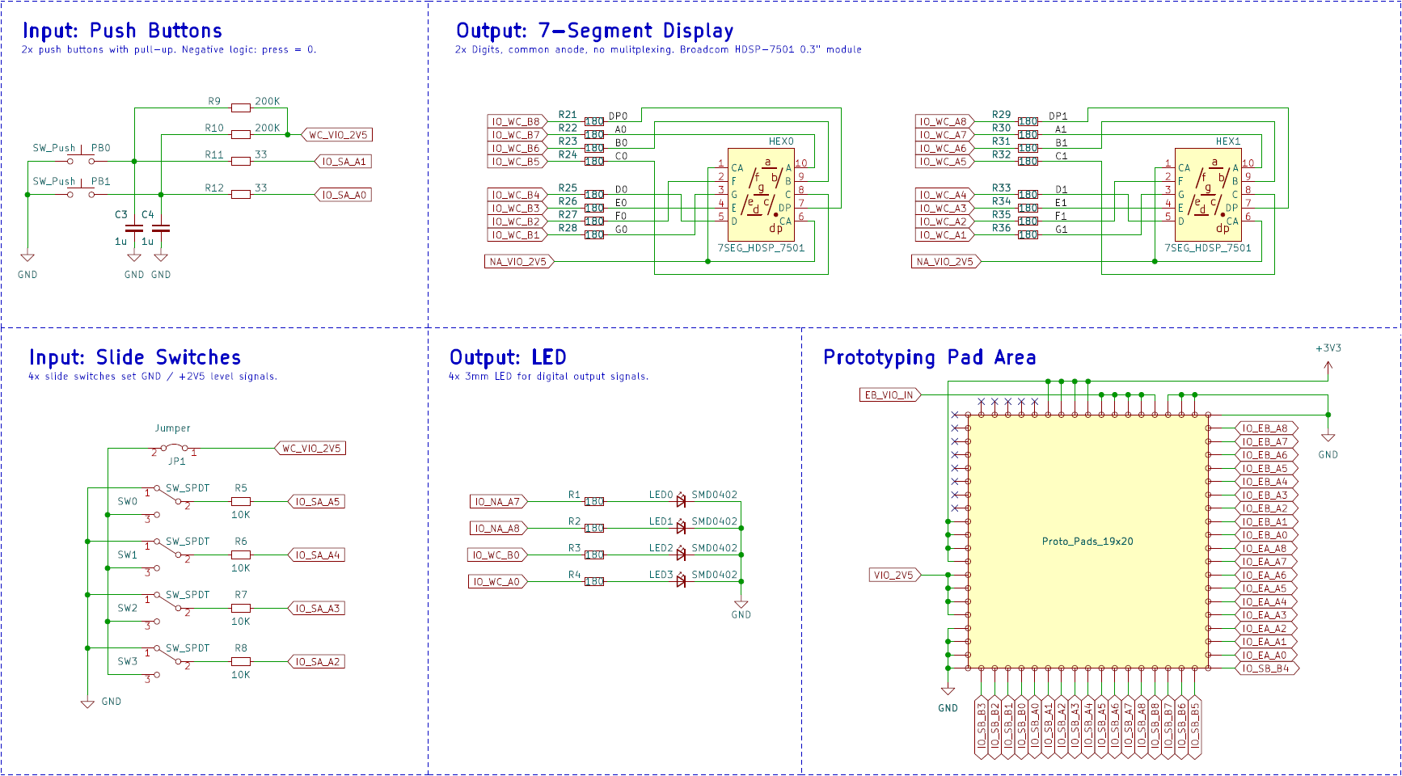
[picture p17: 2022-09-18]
fabfiles-tht/images/schematic.png

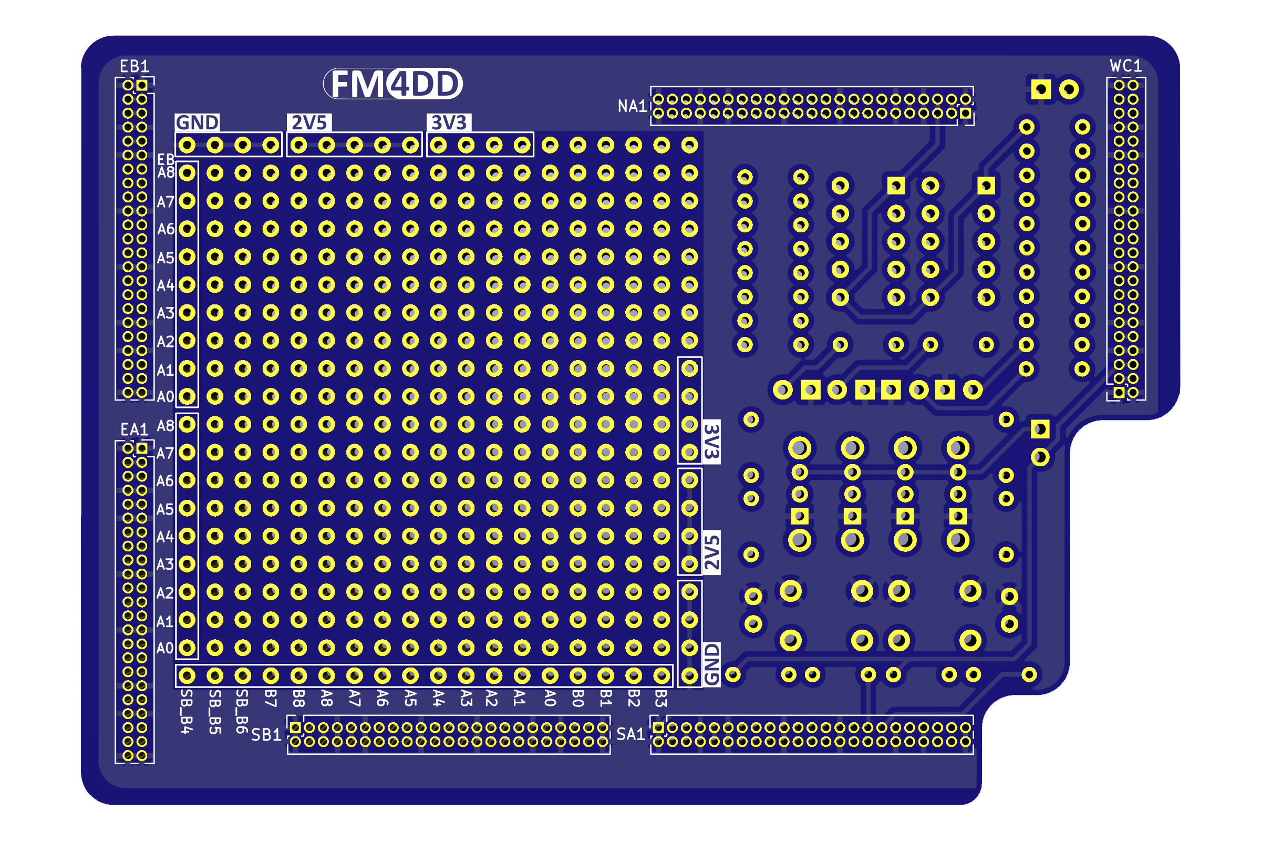
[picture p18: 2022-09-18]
fabfiles-tht/images/gm-proto-e1-back.png

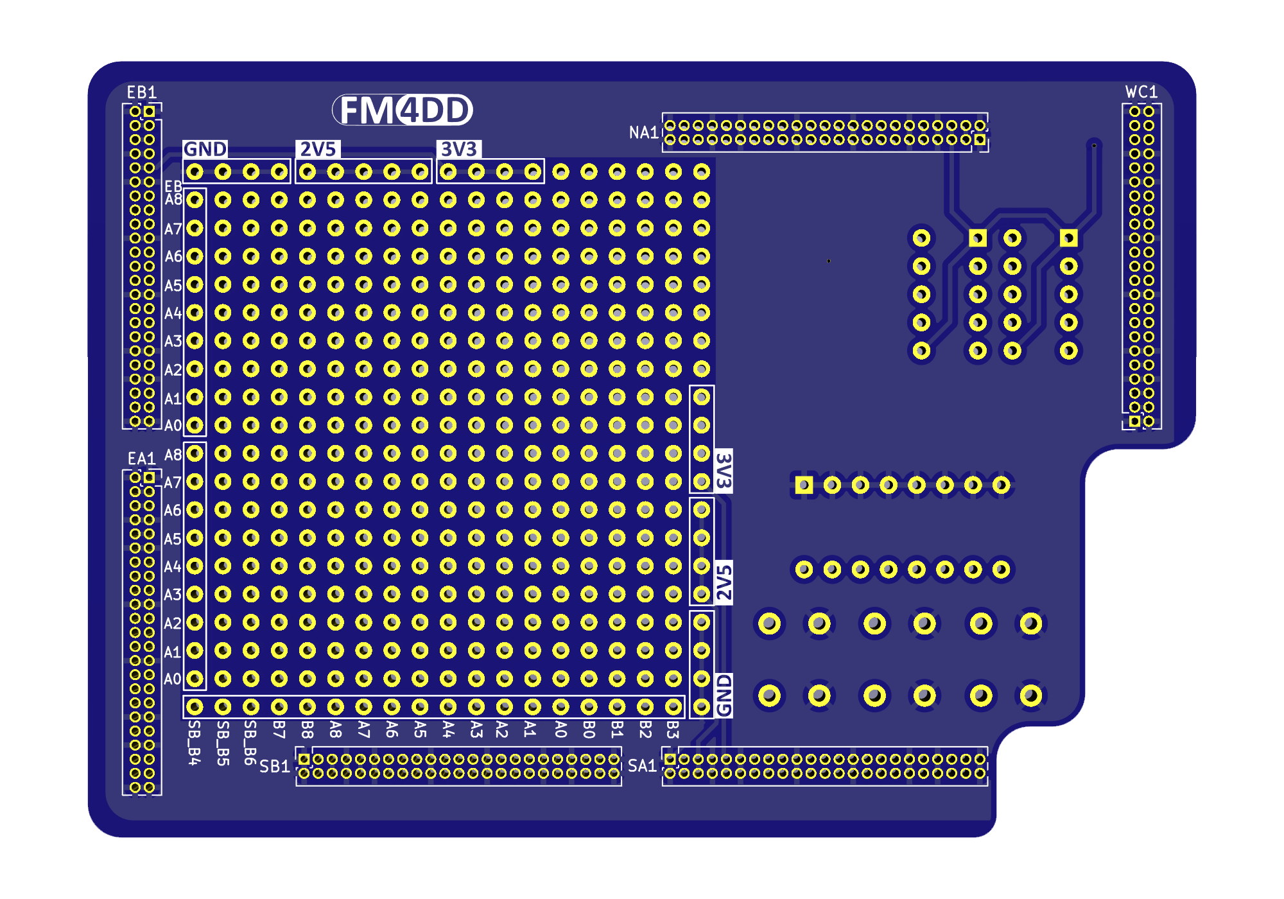
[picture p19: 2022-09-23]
fabfiles-smd/images/gm-proto-e1-back.png

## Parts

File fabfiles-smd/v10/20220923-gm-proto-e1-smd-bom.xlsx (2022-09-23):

Comment | Designator | Footprint | JLCPCB Part #（optional） | Quantity
red TJ-S1005SW4TGLC2R-A5 | LED0,LED1,LED2,LED3,LED4,LED5,LED6,LED7 | LED_0402_FPGA | C273598 | 8
green TJ-S1005SW4TGLC7K-A5 | LED10 | LED_0402_FPGA | C273601 | 1
10K 0402WGF1003TCE | R20,R21,R22,R23,R24,R25,R26,R27 | R_0402_1005Metric | C25741 | 8
33R 0402WGF330JTCE | R16,R17,R18 | R_0402_1005Metric | C25105 | 3
180R | R37 | R_0402_1005Metric |  | 1
200R | R1,R2,R3,R4,R5,R6,R7,R8 | R_0402_1005Metric |  | 8
1u C0402C104K4RECAUTO | C3,C4,C5 | C_0402_1005Metric | C52923 | 3
200K 0402WGF2003TCE | R13,R14,R15 | R_0402_1005Metric | C25764 | 3
Buzzer | BZ1 | Buzzer_Murata_PKLCS1212E | C113159 | 1
180R 4D03WGJ0181T5E | RA1,RA2,RA3,RA4 | R_Array_Convex_4x0603 | C11998 | 4

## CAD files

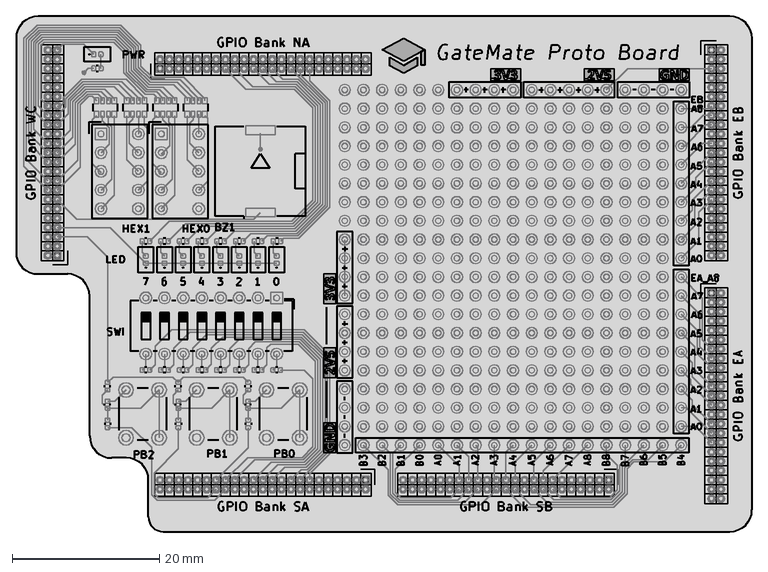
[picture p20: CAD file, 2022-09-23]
fabfiles-smd/cad/gm-proto-e1-dimensions.dxf
100.0 x 70.0 mm

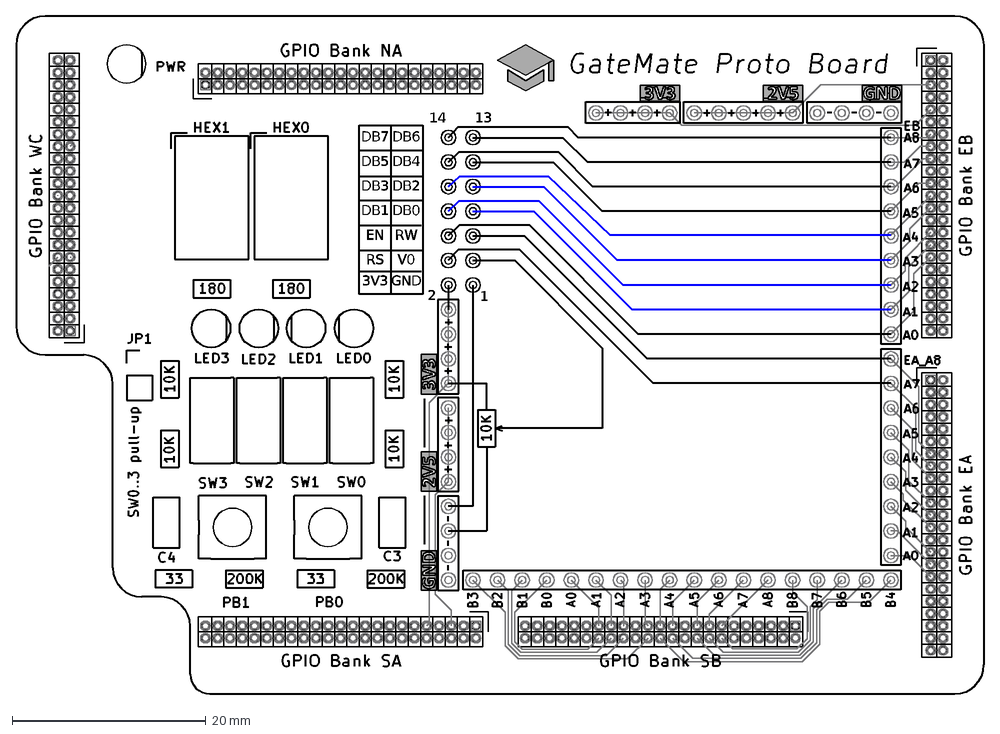
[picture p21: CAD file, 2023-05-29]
fabfiles-tht/cad/gm-proto-e1-charlcd.dxf
1
13
14
2
GND
3V3
V0
RS
RW
EN
DB0
DB2
DB4
DB6
DB1
DB3
DB5
DB7

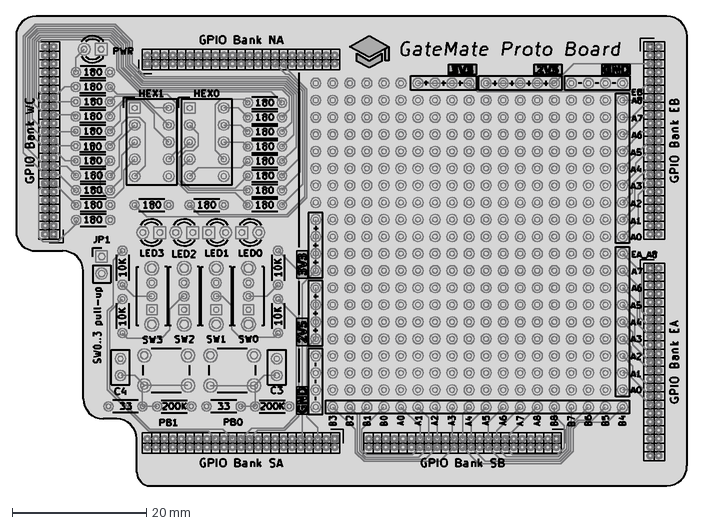
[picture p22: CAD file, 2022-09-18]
fabfiles-tht/cad/gm-proto-e1-dimensions.dxf
100.0 x 70.0 mm

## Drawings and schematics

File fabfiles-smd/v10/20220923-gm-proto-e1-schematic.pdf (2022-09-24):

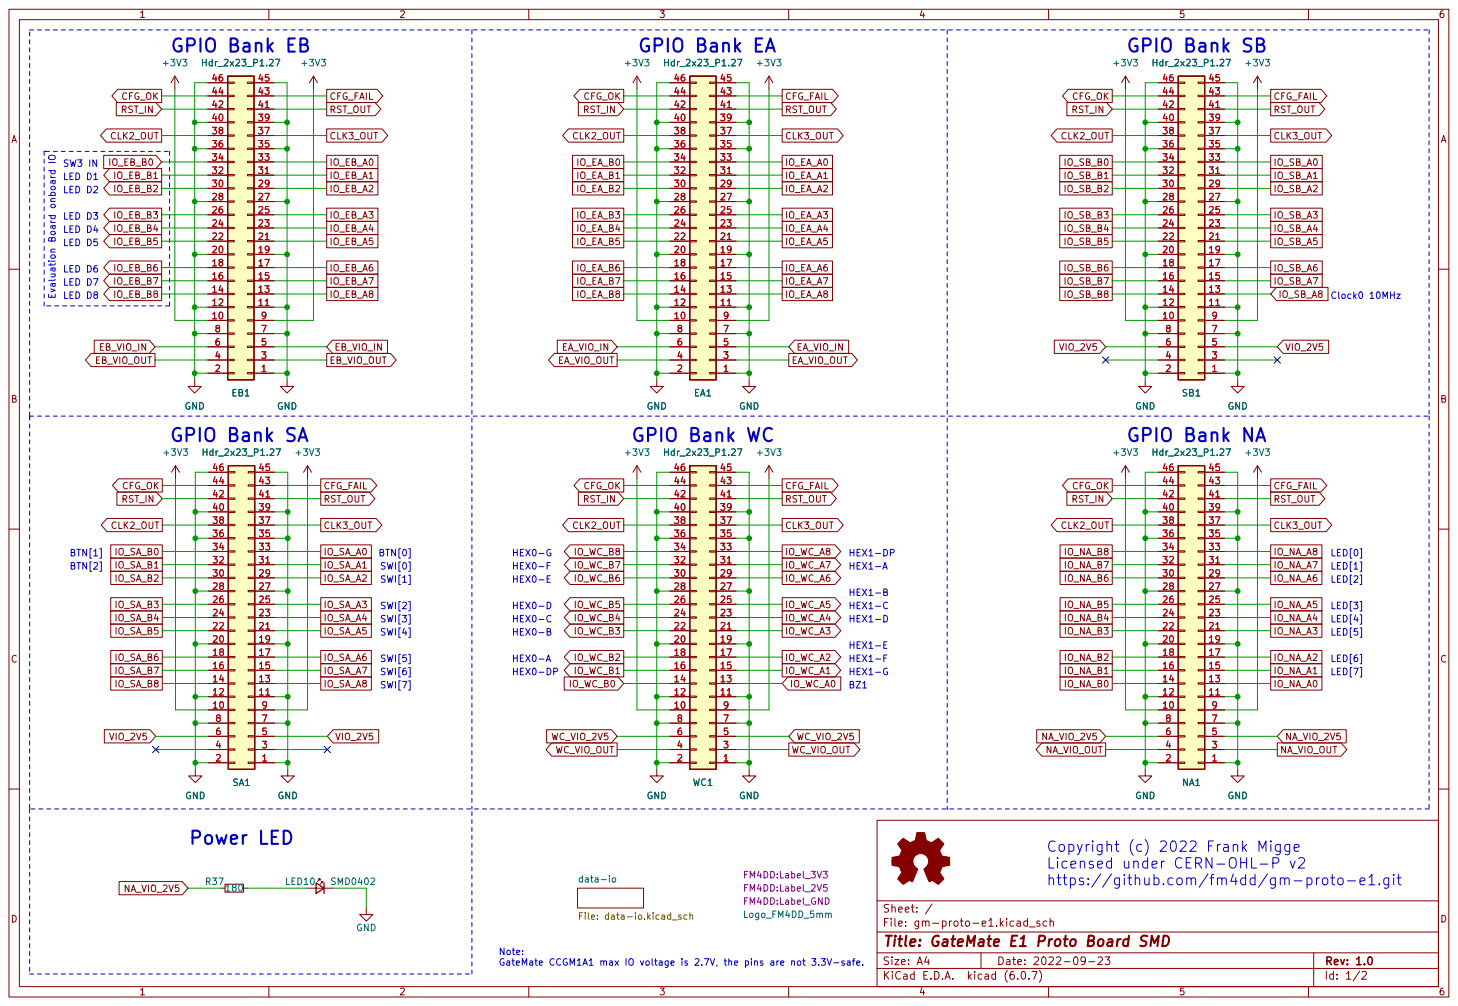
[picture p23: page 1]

Copyright (c) 2022 Frank Migge
Licensed under CERN-OHL-P v2
https://github.com/fm4dd/gm-proto-e1.git

File: gm-proto-e1.kicad_sch Sheet: / data-io File: data-io.kicad_sch

Id: 1/2 Title: GateMate E1 Proto Board SMD

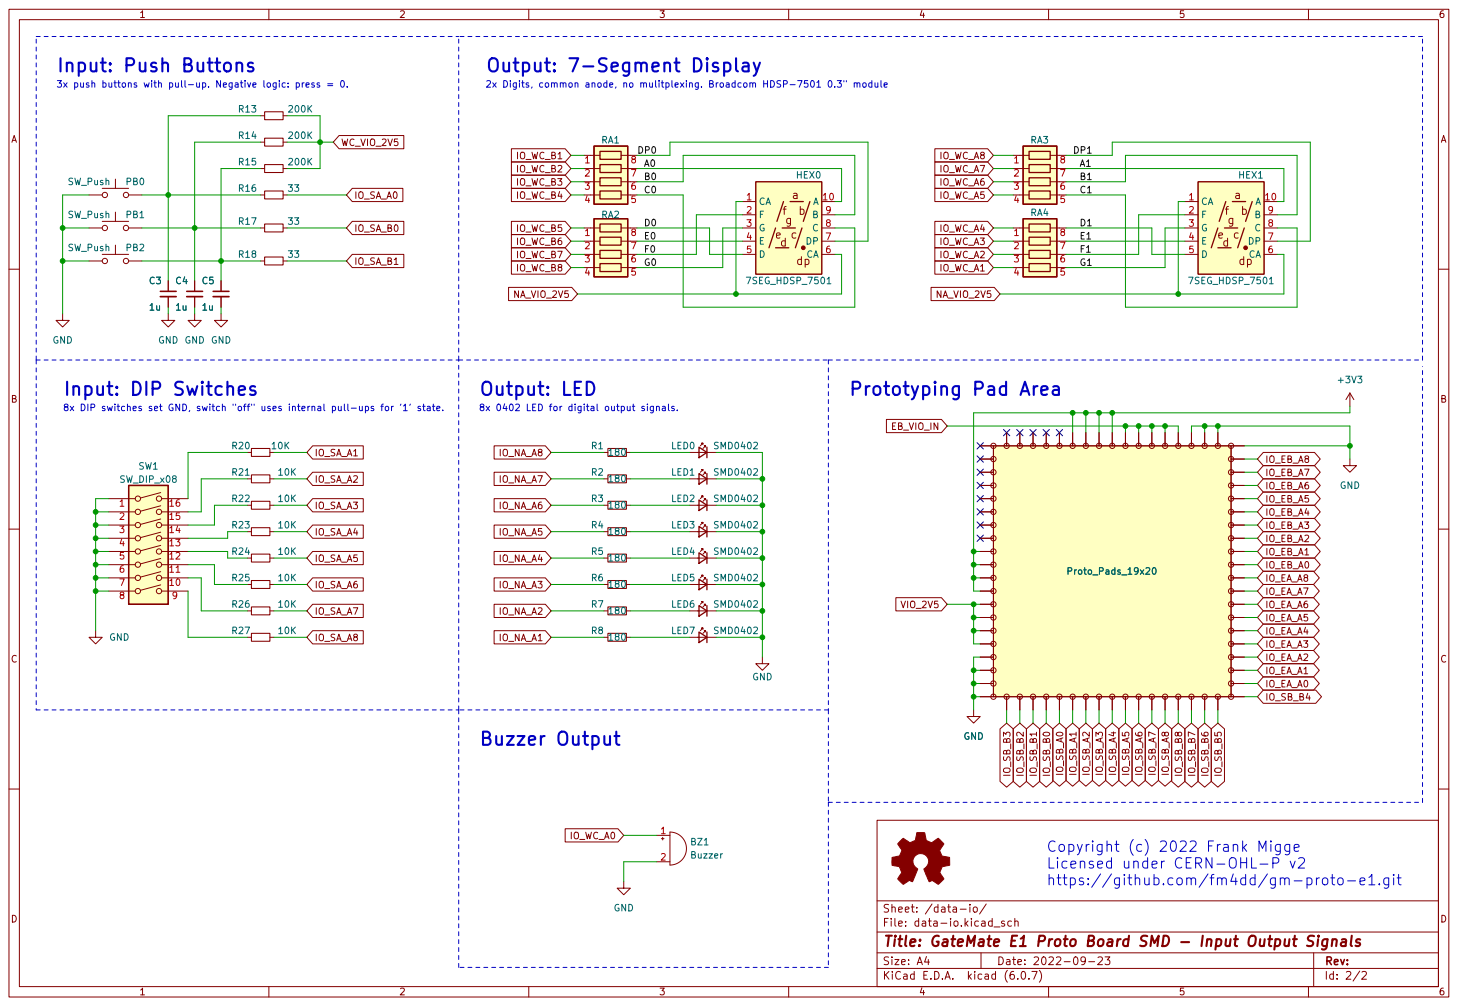
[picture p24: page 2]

3x push buttons with pull-up. Negative logic: press = 0.

2x Digits, common anode, no mulitplexing. Broadcom HDSP-7501 0.3" module

8x DIP switches set GND, switch "off" uses internal pull-ups for '1' state.

8x 0402 LED for digital output signals.

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

File: data-io.kicad_sch Sheet: /data-io/
Id: 2/2 Title: GateMate E1 Proto Board SMD - Input Output Signals

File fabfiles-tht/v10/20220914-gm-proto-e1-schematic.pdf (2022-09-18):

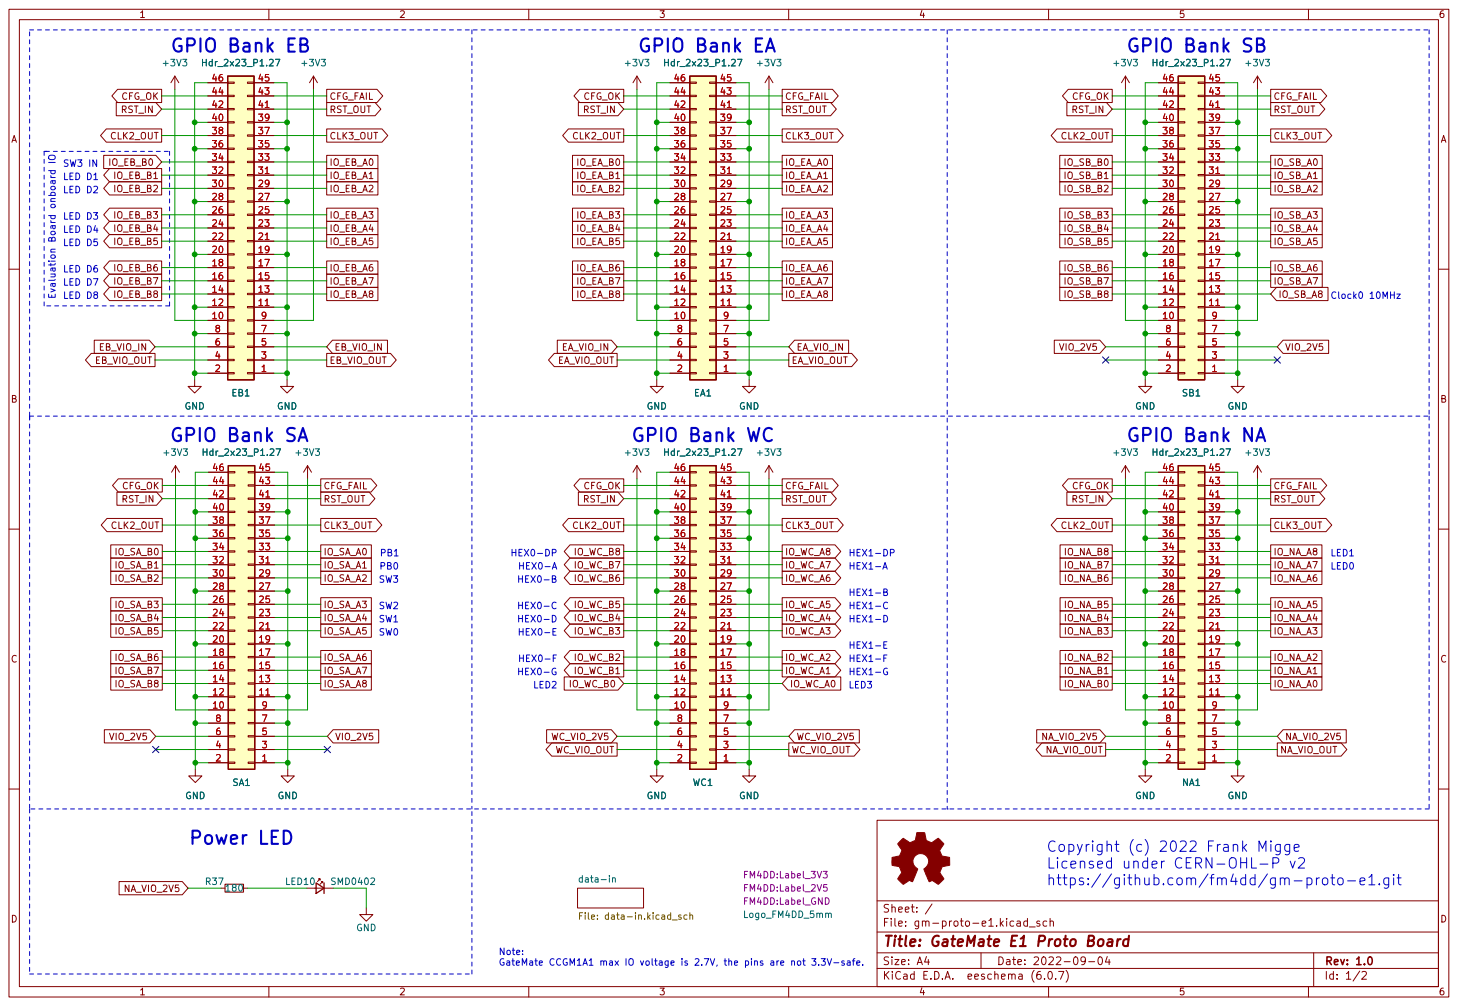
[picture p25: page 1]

Clock0 10MHz GPIO Bank SB Evaluation Board onboard IO
EB1 Hdr_2x23_P1.27

Note: GateMate CCGM1A1 max IO voltage is 2.7V, the pins are not 3.3V-safe. HEX0-A HEX0-B HEX0-E HEX0-F HEX0-C

Licensed under CERN-OHL-P v2

Id: 1/2 Title: GateMate E1 Proto Board

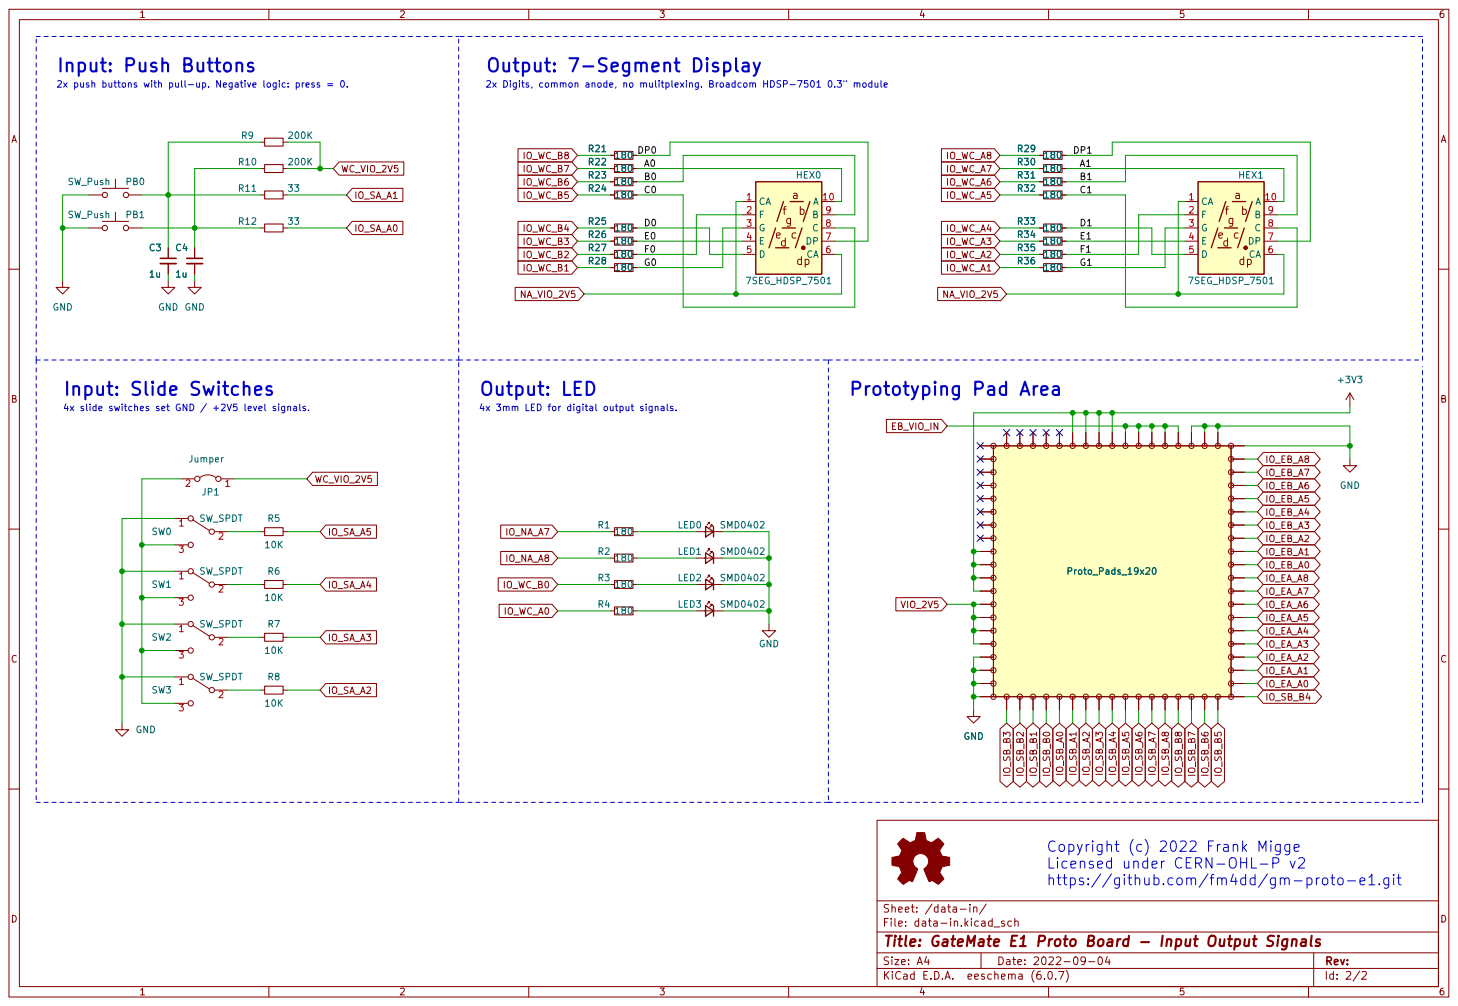
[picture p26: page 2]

2x push buttons with pull-up. Negative logic: press = 0.

2x Digits, common anode, no mulitplexing. Broadcom HDSP-7501 0.3" module

4x slide switches set GND / +2V5 level signals.

4x 3mm LED for digital output signals.

File: data-in.kicad_sch Sheet: /data-in/ R7

https://github.com/fm4dd/gm-proto-e1.git GND

Copyright (c) 2022 Frank Migge
Licensed under CERN-OHL-P v2

Id: 2/2 Title: GateMate E1 Proto Board - Input Output Signals

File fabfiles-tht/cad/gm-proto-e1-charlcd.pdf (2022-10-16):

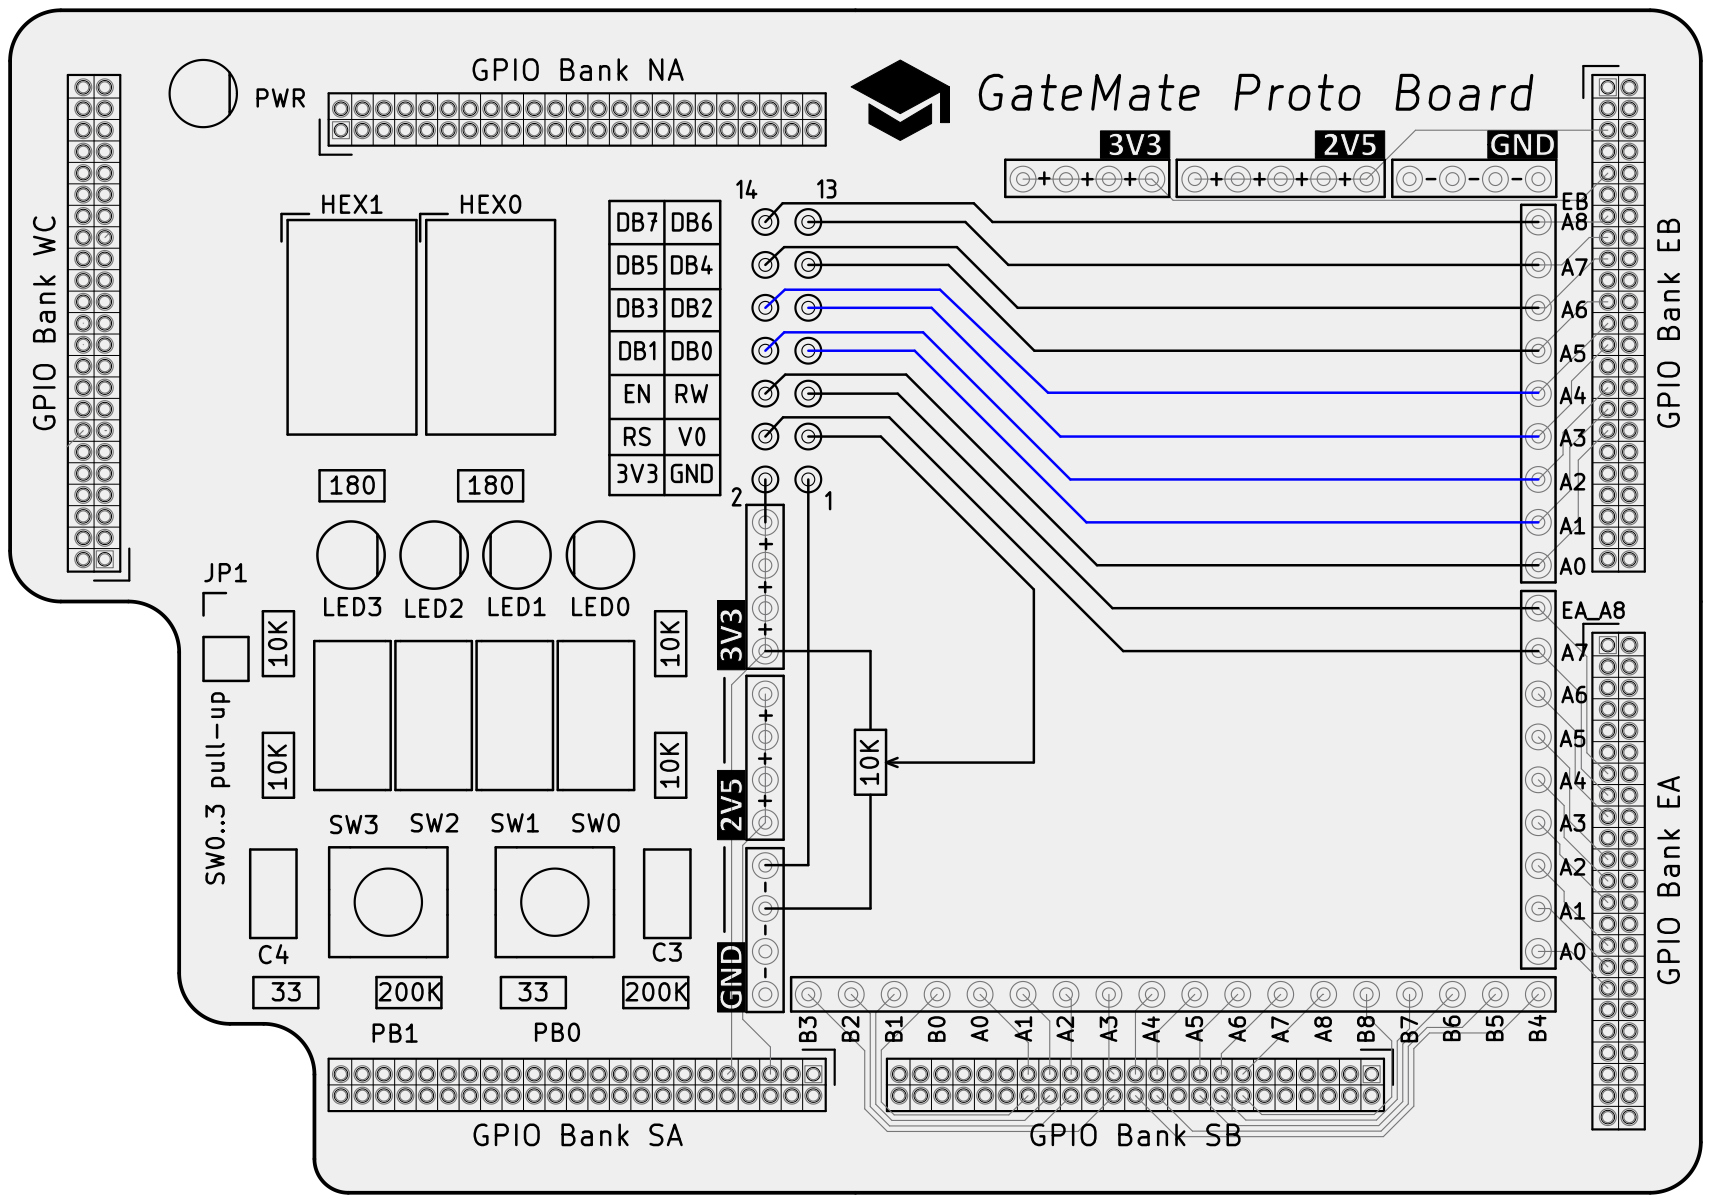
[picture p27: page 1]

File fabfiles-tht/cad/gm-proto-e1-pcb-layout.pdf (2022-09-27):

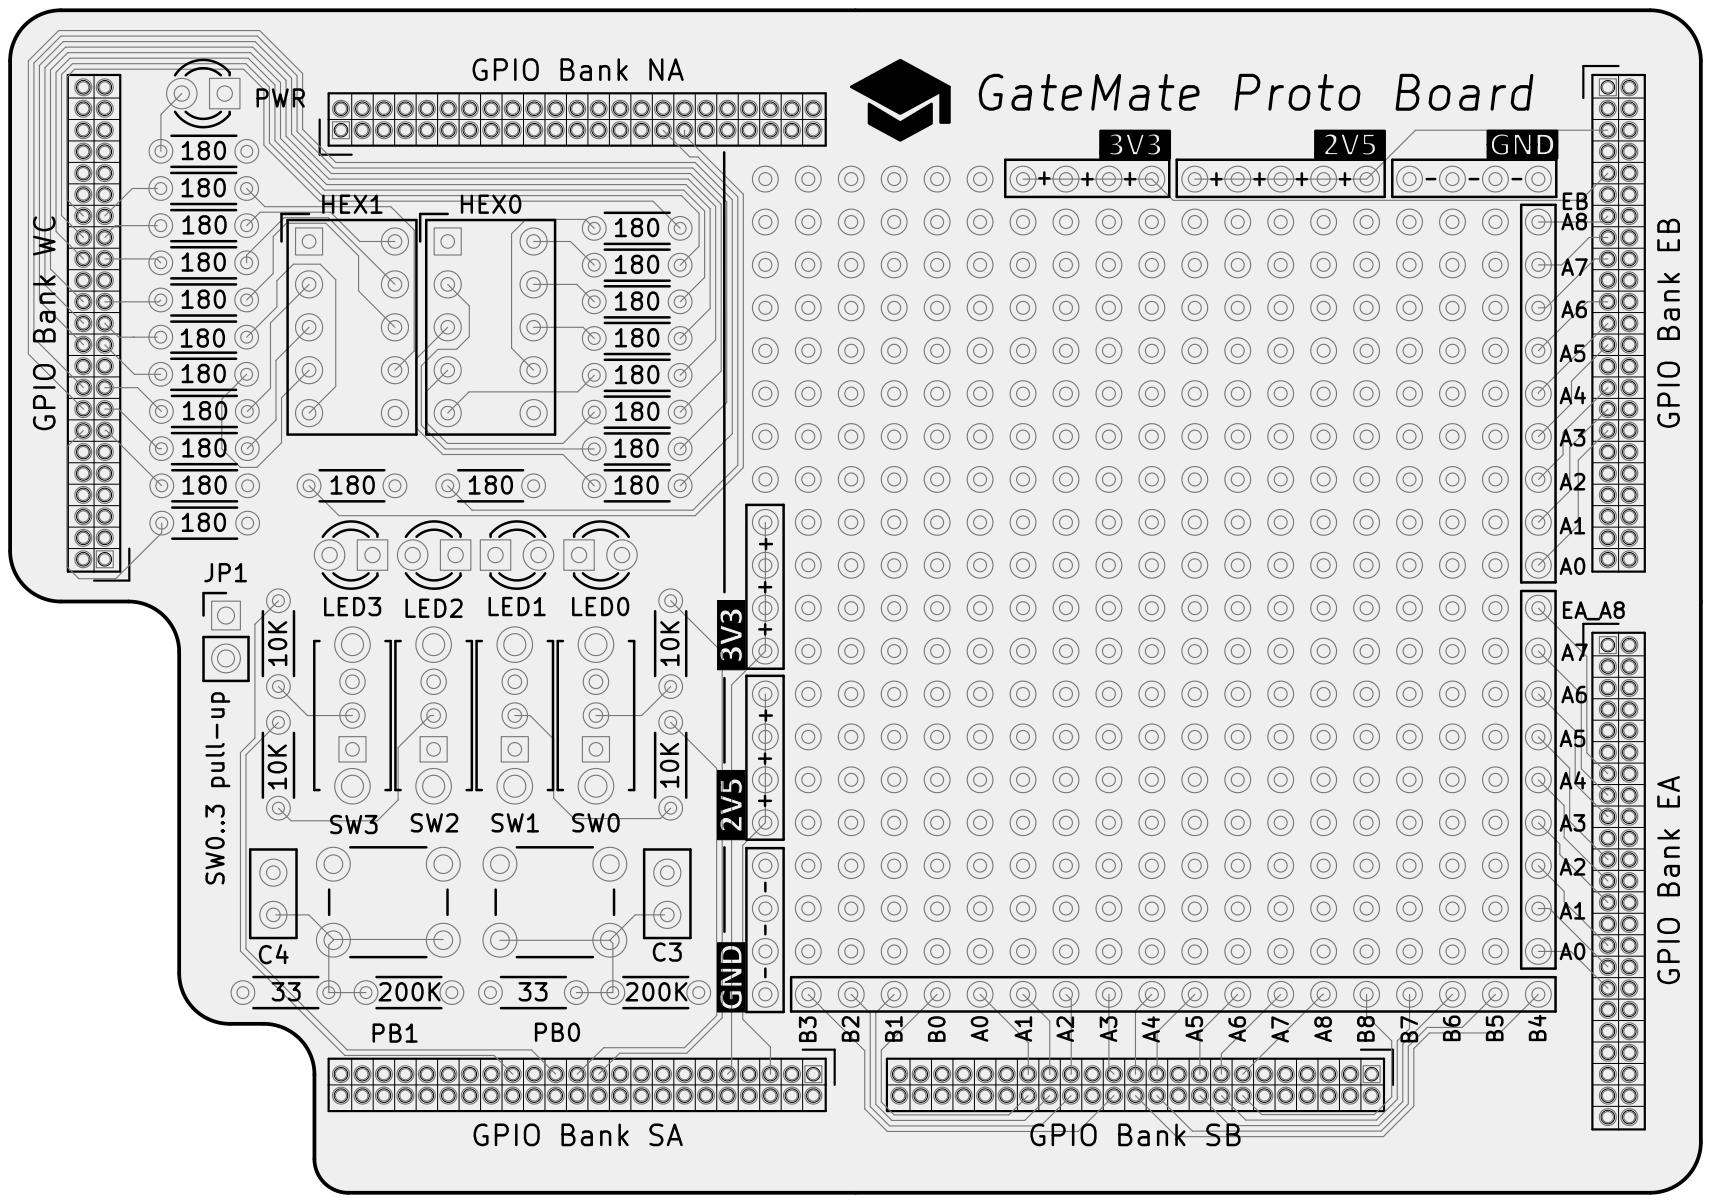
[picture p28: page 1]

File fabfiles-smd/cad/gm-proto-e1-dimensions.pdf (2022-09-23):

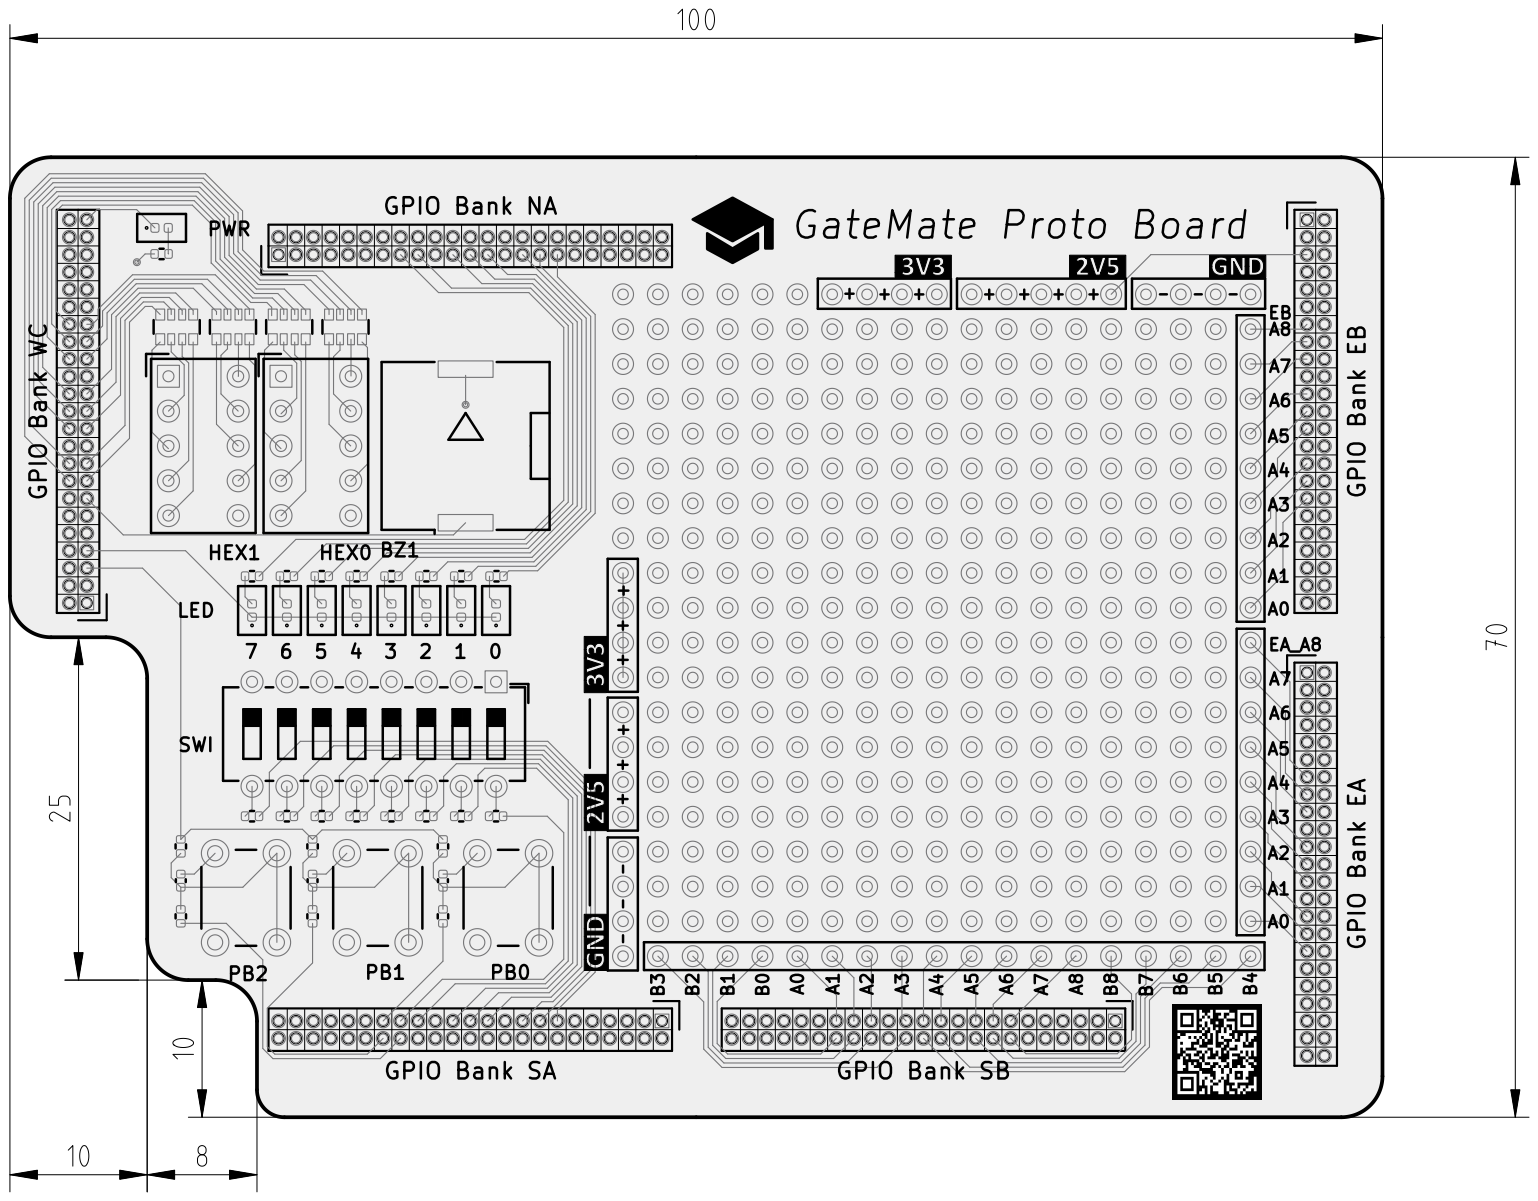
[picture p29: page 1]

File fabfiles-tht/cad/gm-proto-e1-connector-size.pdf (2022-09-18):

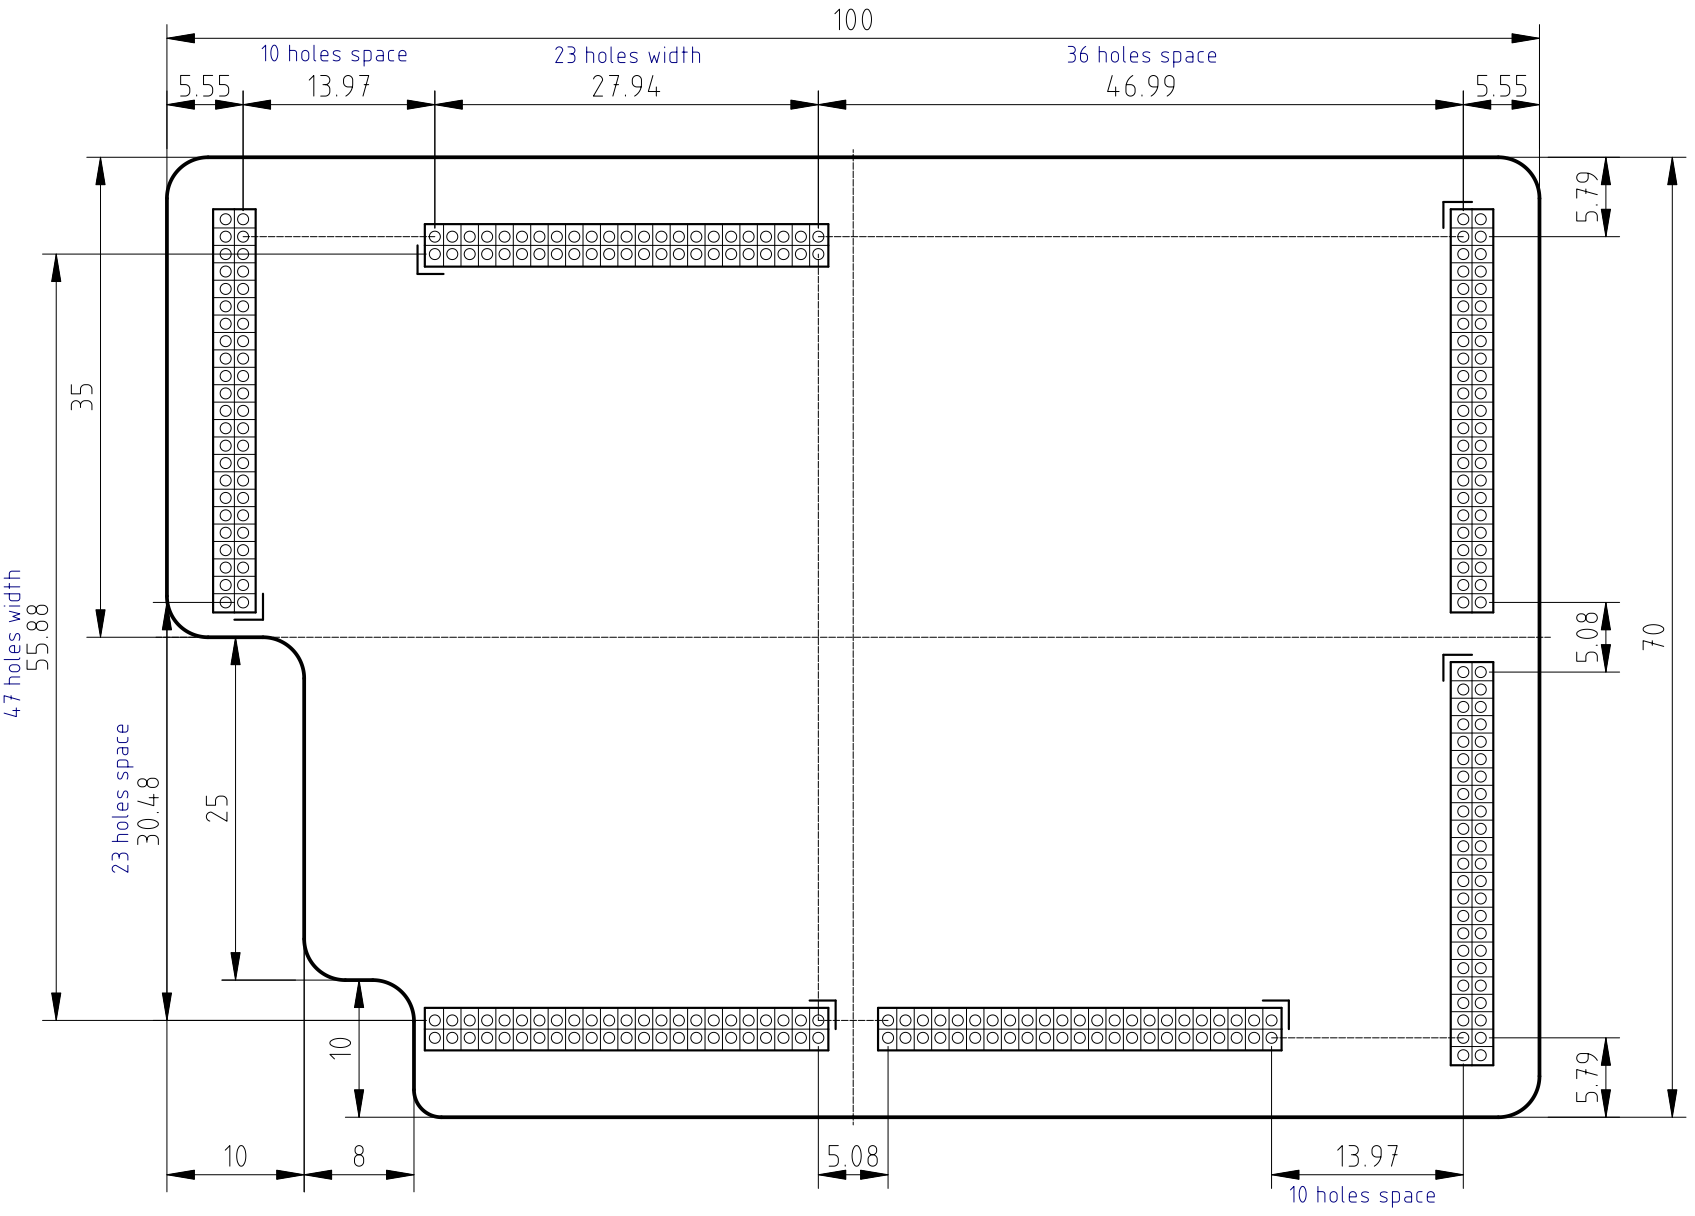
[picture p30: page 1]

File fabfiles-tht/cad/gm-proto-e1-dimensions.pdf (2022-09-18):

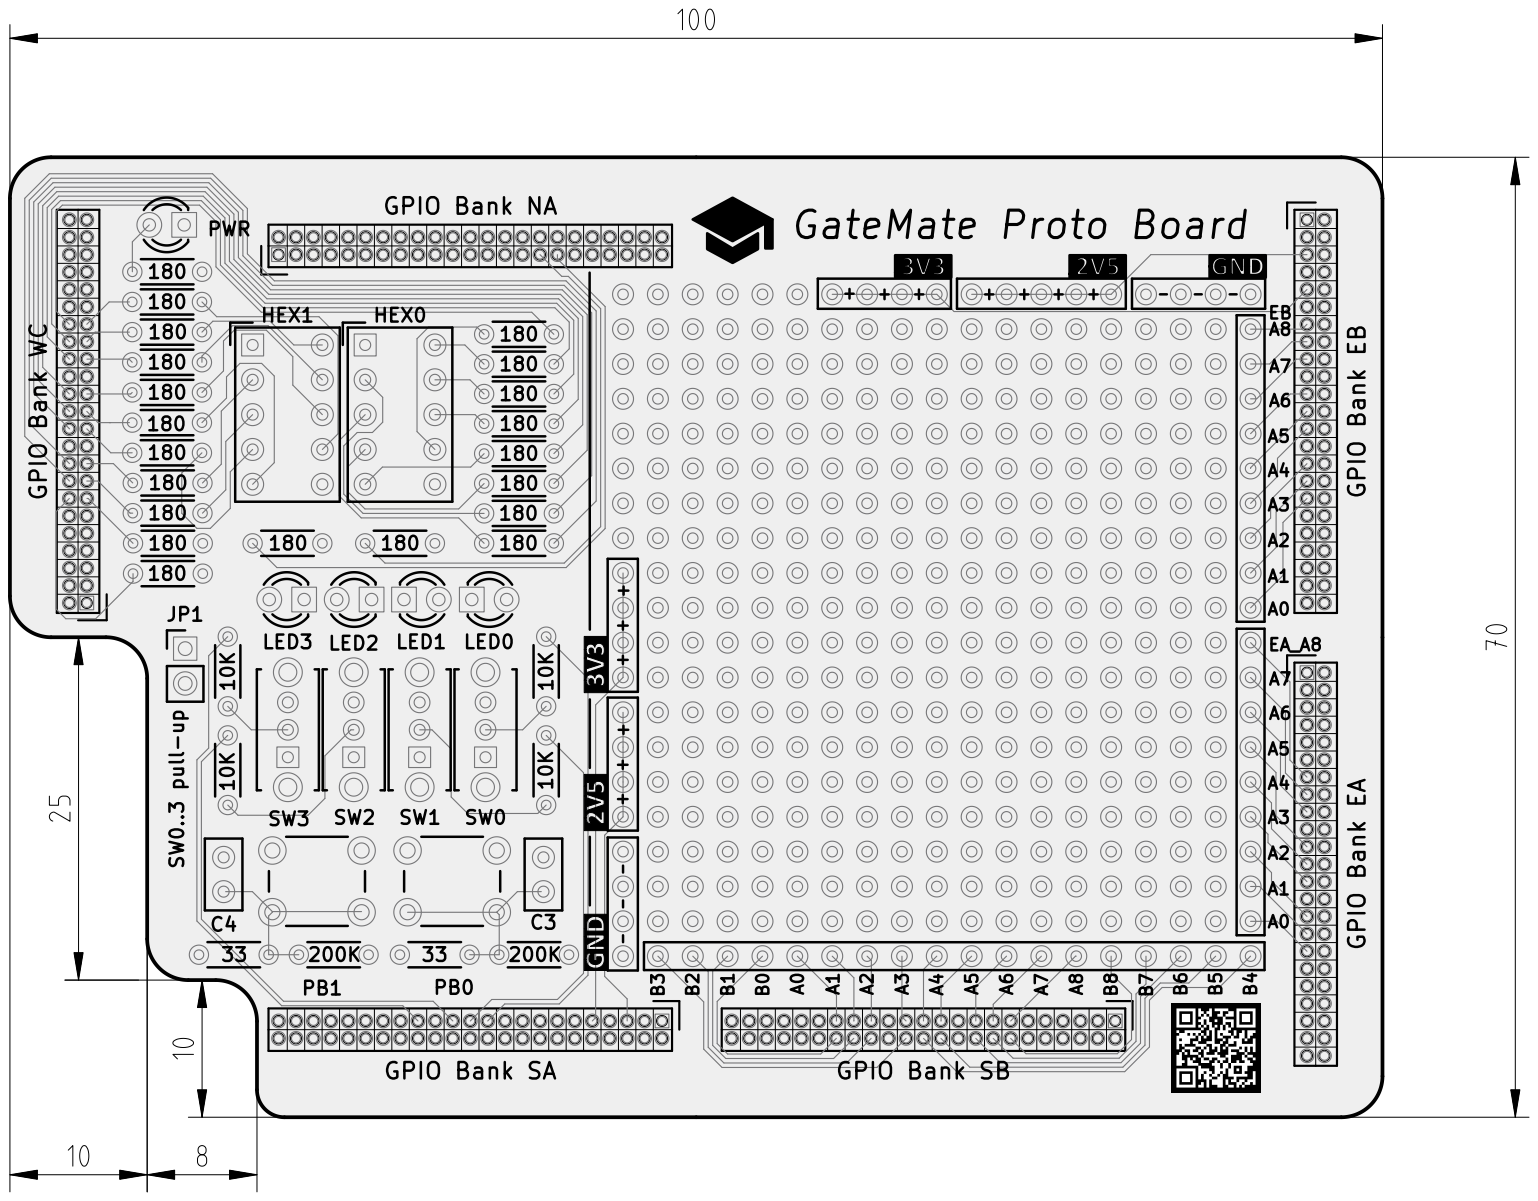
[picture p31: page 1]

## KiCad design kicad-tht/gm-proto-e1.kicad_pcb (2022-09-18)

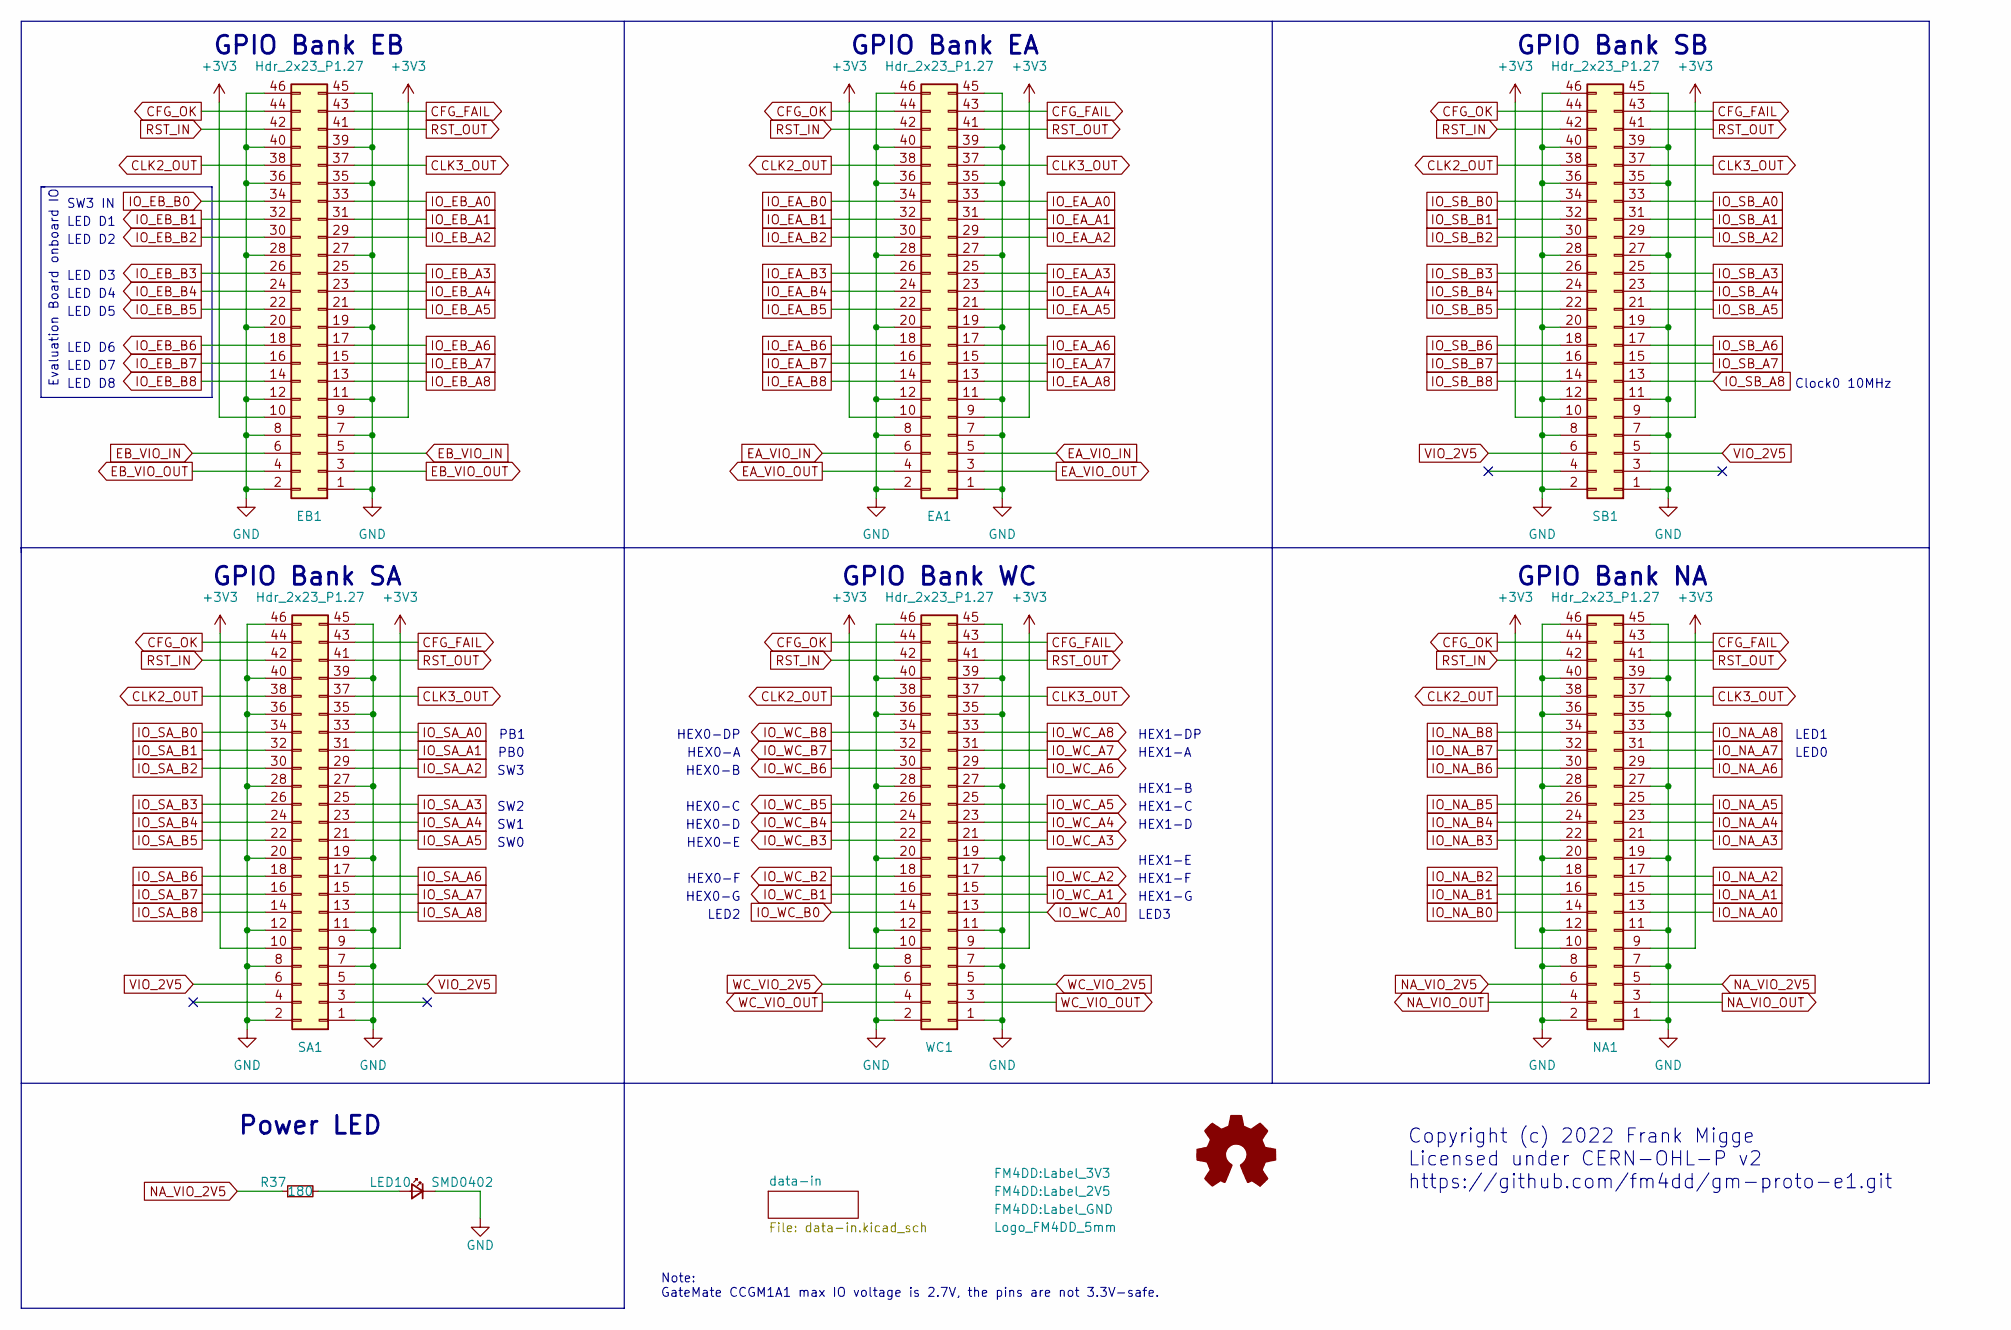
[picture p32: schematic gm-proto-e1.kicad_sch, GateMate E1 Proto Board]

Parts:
EA1: Hdr_2x23_P1.27; PinHeader_2x23_P1.27_backside
EB1: Hdr_2x23_P1.27; PinHeader_2x23_P1.27_backside
LB2: Label_2V5
LB3: Label_GND
LB4: Logo_FM4DD_5mm; Logo_FM4DD_5mm_SScr
LB5: Label_3V3
LED10: SMD0402; LED_D3.0mm
NA1: Hdr_2x23_P1.27; PinHeader_2x23_P1.27_backside
R37: 180; R_Axial_DIN0204_L3.6mm_D1.6mm_P5.08mm_Horizontal
SA1: Hdr_2x23_P1.27; PinHeader_2x23_P1.27_backside
SB1: Hdr_2x23_P1.27; PinHeader_2x23_P1.27_backside
WC1: Hdr_2x23_P1.27; PinHeader_2x23_P1.27_backside

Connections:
+3V3: EA1.9, EA1.10, EB1.9, EB1.10, NA1.9, NA1.10, SA1.9, SA1.10, SB1.9, SB1.10, WC1.9, WC1.10; also elsewhere on the board
CFG_FAIL: EA1.43, EB1.43, NA1.43, SA1.43, SB1.43, WC1.43
CFG_OK: EA1.44, EB1.44, NA1.44, SA1.44, SB1.44, WC1.44
CLK2_OUT: EA1.38, EB1.38, NA1.38, SA1.38, SB1.38, WC1.38
CLK3_OUT: EA1.37, EB1.37, NA1.37, SA1.37, SB1.37, WC1.37
EA_VIO_IN: EA1.5, EA1.6
EA_VIO_OUT: EA1.3, EA1.4
EB_VIO_IN: EB1.5, EB1.6; also elsewhere on the board
EB_VIO_OUT: EB1.3, EB1.4
IO_EA_A0: EA1.33; also elsewhere on the board
IO_EA_A1: EA1.31; also elsewhere on the board
IO_EA_A2: EA1.29; also elsewhere on the board
IO_EA_A3: EA1.25; also elsewhere on the board
IO_EA_A4: EA1.23; also elsewhere on the board
IO_EA_A5: EA1.21; also elsewhere on the board
IO_EA_A6: EA1.17; also elsewhere on the board
IO_EA_A7: EA1.15; also elsewhere on the board
IO_EA_A8: EA1.13; also elsewhere on the board
IO_EA_B0: EA1.34
IO_EA_B1: EA1.32
IO_EA_B2: EA1.30
IO_EA_B3: EA1.26
IO_EA_B4: EA1.24
IO_EA_B5: EA1.22
IO_EA_B6: EA1.18
IO_EA_B7: EA1.16
IO_EA_B8: EA1.14
IO_EB_A0: EB1.33; also elsewhere on the board
IO_EB_A1: EB1.31; also elsewhere on the board
IO_EB_A2: EB1.29; also elsewhere on the board
IO_EB_A3: EB1.25; also elsewhere on the board
IO_EB_A4: EB1.23; also elsewhere on the board
IO_EB_A5: EB1.21; also elsewhere on the board
IO_EB_A6: EB1.17; also elsewhere on the board
IO_EB_A7: EB1.15; also elsewhere on the board
IO_EB_A8: EB1.13; also elsewhere on the board
IO_EB_B0: EB1.34
IO_EB_B1: EB1.32
IO_EB_B2: EB1.30
IO_EB_B3: EB1.26
IO_EB_B4: EB1.24
IO_EB_B5: EB1.22
IO_EB_B6: EB1.18
IO_EB_B7: EB1.16
IO_EB_B8: EB1.14
IO_NA_A0: NA1.13
IO_NA_A1: NA1.15
IO_NA_A2: NA1.17
IO_NA_A3: NA1.21
IO_NA_A4: NA1.23
IO_NA_A5: NA1.25
IO_NA_A6: NA1.29
IO_NA_A7: NA1.31; also elsewhere on the board
IO_NA_A8: NA1.33; also elsewhere on the board
IO_NA_B0: NA1.14
IO_NA_B1: NA1.16
IO_NA_B2: NA1.18
IO_NA_B3: NA1.22
IO_NA_B4: NA1.24
IO_NA_B5: NA1.26
IO_NA_B6: NA1.30
IO_NA_B7: NA1.32
IO_NA_B8: NA1.34
IO_SA_A0: SA1.33; also elsewhere on the board
IO_SA_A1: SA1.31; also elsewhere on the board
IO_SA_A2: SA1.29; also elsewhere on the board
IO_SA_A3: SA1.25; also elsewhere on the board
IO_SA_A4: SA1.23; also elsewhere on the board
IO_SA_A5: SA1.21; also elsewhere on the board
IO_SA_A6: SA1.17
IO_SA_A7: SA1.15
IO_SA_A8: SA1.13
IO_SA_B0: SA1.34
IO_SA_B1: SA1.32
IO_SA_B2: SA1.30
IO_SA_B3: SA1.26
IO_SA_B4: SA1.24
IO_SA_B5: SA1.22
IO_SA_B6: SA1.18
IO_SA_B7: SA1.16
IO_SA_B8: SA1.14
IO_SB_A0: SB1.33; also elsewhere on the board
IO_SB_A1: SB1.31; also elsewhere on the board
IO_SB_A2: SB1.29; also elsewhere on the board
IO_SB_A3: SB1.25; also elsewhere on the board
IO_SB_A4: SB1.23; also elsewhere on the board
IO_SB_A5: SB1.21; also elsewhere on the board
IO_SB_A6: SB1.17; also elsewhere on the board
IO_SB_A7: SB1.15; also elsewhere on the board
IO_SB_A8: SB1.13; also elsewhere on the board
IO_SB_B0: SB1.34; also elsewhere on the board
IO_SB_B1: SB1.32; also elsewhere on the board
IO_SB_B2: SB1.30; also elsewhere on the board
IO_SB_B3: SB1.26; also elsewhere on the board
IO_SB_B4: SB1.24; also elsewhere on the board
IO_SB_B5: SB1.22; also elsewhere on the board
IO_SB_B6: SB1.18; also elsewhere on the board
IO_SB_B7: SB1.16; also elsewhere on the board
IO_SB_B8: SB1.14; also elsewhere on the board
IO_WC_A0: WC1.13; also elsewhere on the board
IO_WC_A1: WC1.15; also elsewhere on the board
IO_WC_A2: WC1.17; also elsewhere on the board
IO_WC_A3: WC1.21; also elsewhere on the board
IO_WC_A4: WC1.23; also elsewhere on the board
IO_WC_A5: WC1.25; also elsewhere on the board
IO_WC_A6: WC1.29; also elsewhere on the board
IO_WC_A7: WC1.31; also elsewhere on the board
IO_WC_A8: WC1.33; also elsewhere on the board
IO_WC_B0: WC1.14; also elsewhere on the board
IO_WC_B1: WC1.16; also elsewhere on the board
IO_WC_B2: WC1.18; also elsewhere on the board
IO_WC_B3: WC1.22; also elsewhere on the board
IO_WC_B4: WC1.24; also elsewhere on the board
IO_WC_B5: WC1.26; also elsewhere on the board
IO_WC_B6: WC1.30; also elsewhere on the board
IO_WC_B7: WC1.32; also elsewhere on the board
IO_WC_B8: WC1.34; also elsewhere on the board
NA_VIO_2V5: NA1.5, NA1.6, R37.1; also elsewhere on the board
NA_VIO_OUT: NA1.3, NA1.4
unnamed: LED10.2 (A), R37.2
RST_IN: EA1.42, EB1.42, NA1.42, SA1.42, SB1.42, WC1.42
RST_OUT: EA1.41, EB1.41, NA1.41, SA1.41, SB1.41, WC1.41
VIO_2V5: SA1.5, SA1.6, SB1.5, SB1.6; also elsewhere on the board
WC_VIO_OUT: WC1.3, WC1.4

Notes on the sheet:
HEX0-A
SW1
LED1
HEX0-B
HEX0-E
LED D3
Note: GateMate CCGM1A1 max IO voltage is 2.7V, the pins are not 3.3V-safe.
LED D7
LED D2
HEX1-F
SW3 IN
HEX0-F
LED D8
Clock0 10MHz
LED D4
HEX1-G
SW0
GPIO Bank NA
LED2
Evaluation Board onboard IO
SW3
HEX1-D
HEX0-C
GPIO Bank SB
GPIO Bank SA
PB0
PB1
HEX0-G
HEX1-A
GPIO Bank EB
HEX0-DP
LED D5
HEX1-C
LED D6
HEX1-E
GPIO Bank WC
HEX1-DP
LED D1
Copyright (c) 2022 Frank Migge Licensed under CERN-OHL-P v2 https://github.com/fm4dd/gm-proto-e1.git
HEX1-B

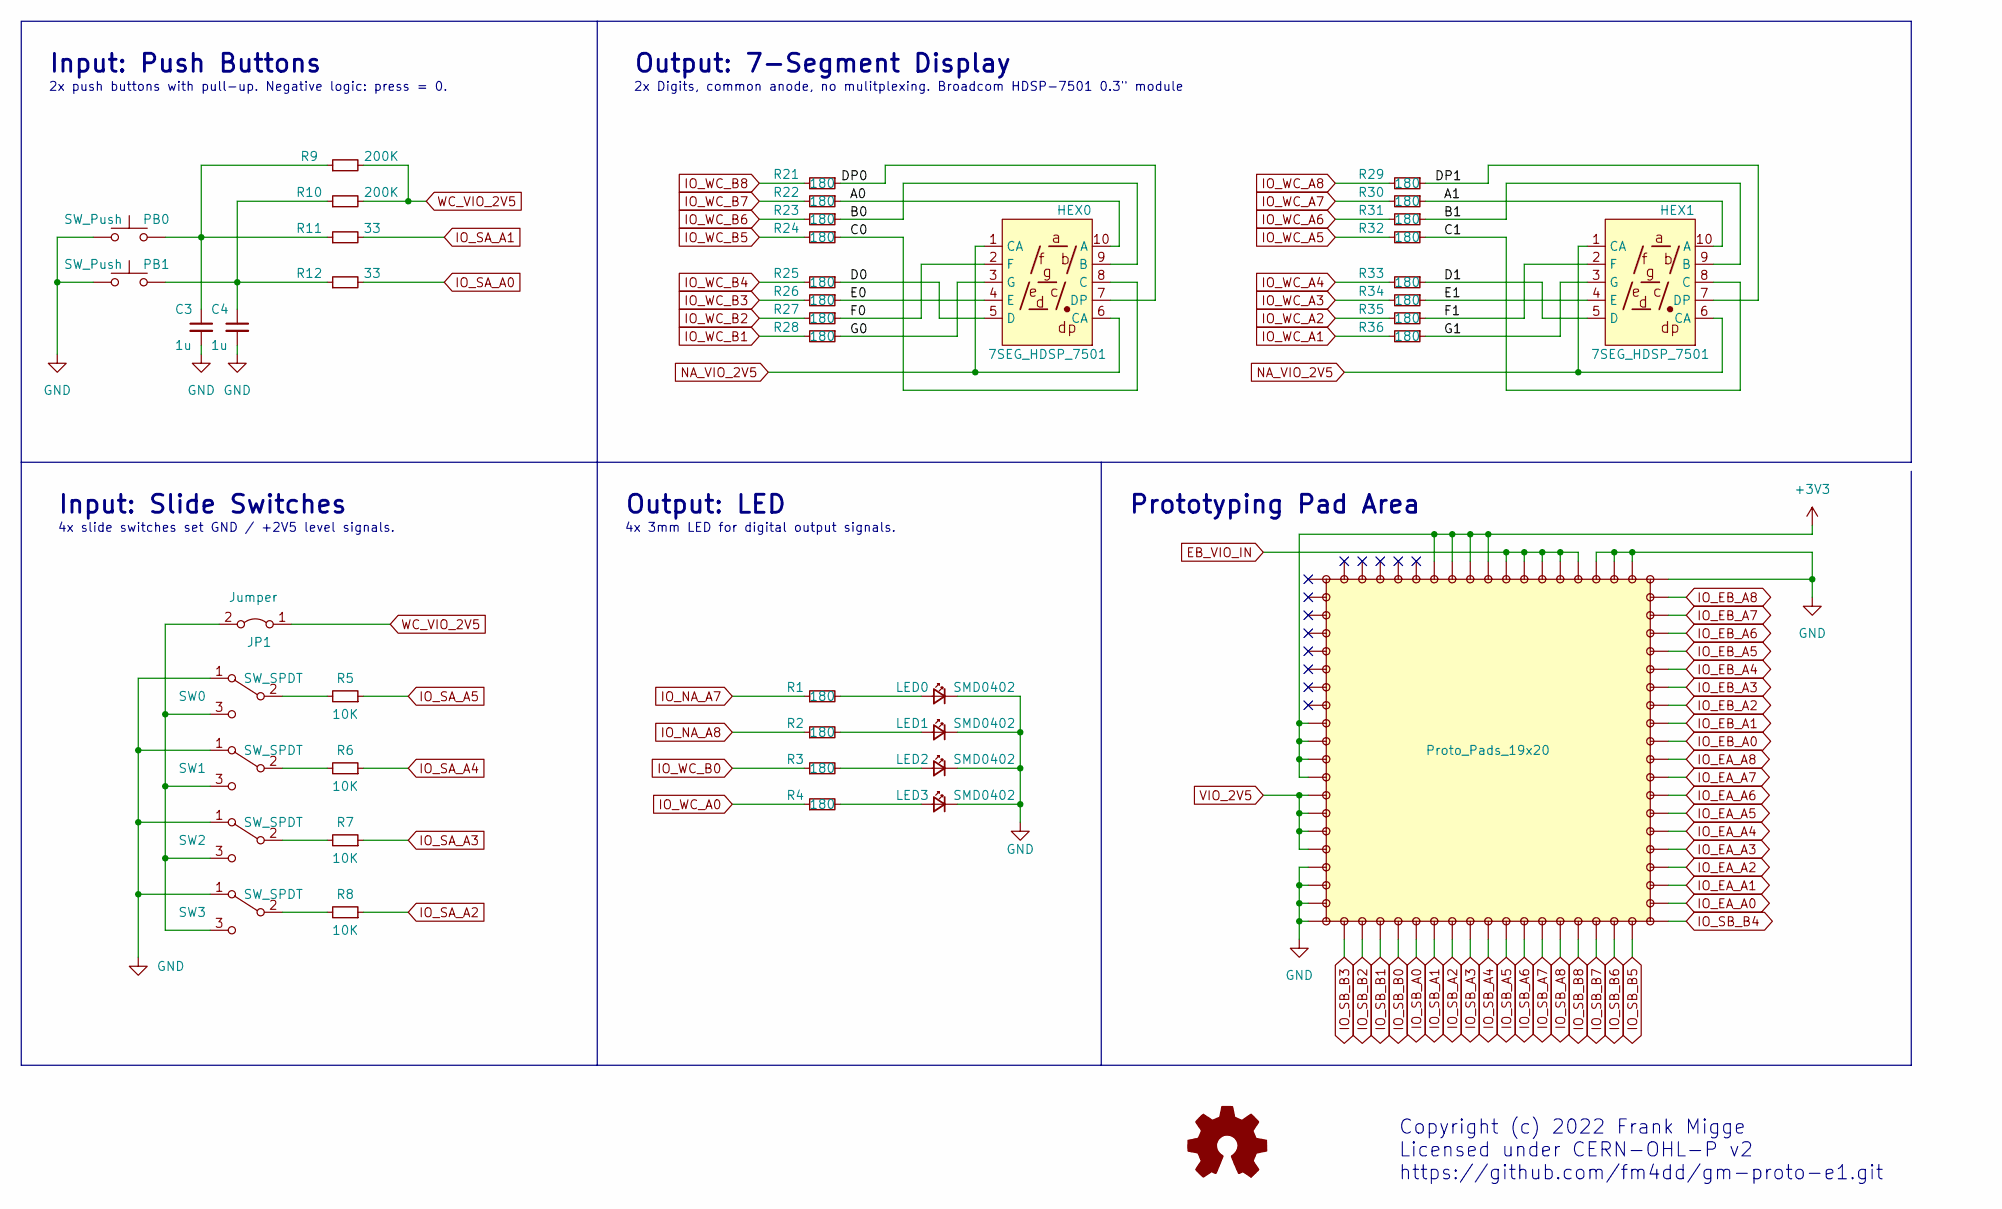
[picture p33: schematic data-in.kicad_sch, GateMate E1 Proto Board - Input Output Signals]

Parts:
C3, C4: 1u; C_Disc_D5.0mm_W2.5mm_P2.50mm
H1: Proto_Pads_19x20; Proto_Pad_Array_19x20
HEX0, HEX1: 7SEG_HDSP_7501; HDSP-7401
JP1: Jumper; PinHeader_1x02_P2.54mm_Vertical
LED0, LED1, LED2, LED3: SMD0402; LED_D3.0mm
PB0, PB1: SW_Push; SW_PUSH_6mm
R1, R2, R3, R4, R21, R22, R23, R24, R25, R26, R27, R28, R29, R30, R31, R32, R33, R34, R35, R36: 180; R_Axial_DIN0204_L3.6mm_D1.6mm_P5.08mm_Horizontal
R5, R6, R7, R8: 10K; R_Axial_DIN0204_L3.6mm_D1.6mm_P5.08mm_Horizontal
R9, R10: 200K; R_Axial_DIN0204_L3.6mm_D1.6mm_P5.08mm_Horizontal
R11, R12: 33; R_Axial_DIN0204_L3.6mm_D1.6mm_P5.08mm_Horizontal
SW0, SW1, SW2, SW3: SW_SPDT; SlideSW_SS12-D01

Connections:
+3V3: H1.29 (p29), H1.30 (p30), H1.31 (p31), H1.32 (p32), H1.46 (p46), H1.47 (p47), H1.48 (p48), H1.49 (p49); also elsewhere on the board
/data-in/A0: HEX0.10 (A), R22.1
/data-in/A1: HEX1.10 (A), R30.1
/data-in/B0: HEX0.9 (B), R23.1
/data-in/B1: HEX1.9 (B), R31.1
/data-in/C0: HEX0.8 (C), R24.1
/data-in/C1: HEX1.8 (C), R32.1
/data-in/D0: HEX0.5 (D), R25.1
/data-in/D1: HEX1.5 (D), R33.1
/data-in/DP0: HEX0.7 (DP), R21.1
/data-in/DP1: HEX1.7 (DP), R29.1
/data-in/E0: HEX0.4 (E), R26.1
/data-in/E1: HEX1.4 (E), R34.1
/data-in/F0: HEX0.2 (F), R27.1
/data-in/F1: HEX1.2 (F), R35.1
/data-in/G0: HEX0.3 (G), R28.1
/data-in/G1: HEX1.3 (G), R36.1
EB_VIO_IN: H1.24 (p24), H1.25 (p25), H1.26 (p26), H1.27 (p27), H1.28 (p28); also elsewhere on the board
IO_EA_A0: H1.2 (p2); also elsewhere on the board
IO_EA_A1: H1.3 (p3); also elsewhere on the board
IO_EA_A2: H1.4 (p4); also elsewhere on the board
IO_EA_A3: H1.5 (p5); also elsewhere on the board
IO_EA_A4: H1.6 (p6); also elsewhere on the board
IO_EA_A5: H1.7 (p7); also elsewhere on the board
IO_EA_A6: H1.8 (p8); also elsewhere on the board
IO_EA_A7: H1.9 (p9); also elsewhere on the board
IO_EA_A8: H1.10 (p10); also elsewhere on the board
IO_EB_A0: H1.11 (p11); also elsewhere on the board
IO_EB_A1: H1.12 (p12); also elsewhere on the board
IO_EB_A2: H1.13 (p13); also elsewhere on the board
IO_EB_A3: H1.14 (p14); also elsewhere on the board
IO_EB_A4: H1.15 (p15); also elsewhere on the board
IO_EB_A5: H1.16 (p16); also elsewhere on the board
IO_EB_A6: H1.17 (p17); also elsewhere on the board
IO_EB_A7: H1.18 (p18); also elsewhere on the board
IO_EB_A8: H1.19 (p19); also elsewhere on the board
IO_NA_A7: R1.1; also elsewhere on the board
IO_NA_A8: R2.1; also elsewhere on the board
IO_SA_A0: R12.2; also elsewhere on the board
IO_SA_A1: R11.2; also elsewhere on the board
IO_SA_A2: R8.1; also elsewhere on the board
IO_SA_A3: R7.1; also elsewhere on the board
IO_SA_A4: R6.1; also elsewhere on the board
IO_SA_A5: R5.1; also elsewhere on the board
IO_SB_A0: H1.62 (p62); also elsewhere on the board
IO_SB_A1: H1.63 (p63); also elsewhere on the board
IO_SB_A2: H1.64 (p64); also elsewhere on the board
IO_SB_A3: H1.65 (p65); also elsewhere on the board
IO_SB_A4: H1.66 (p66); also elsewhere on the board
IO_SB_A5: H1.67 (p67); also elsewhere on the board
IO_SB_A6: H1.68 (p68); also elsewhere on the board
IO_SB_A7: H1.69 (p69); also elsewhere on the board
IO_SB_A8: H1.70 (p70); also elsewhere on the board
IO_SB_B0: H1.61 (p61); also elsewhere on the board
IO_SB_B1: H1.60 (p60); also elsewhere on the board
IO_SB_B2: H1.59 (p59); also elsewhere on the board
IO_SB_B3: H1.58 (p58); also elsewhere on the board
IO_SB_B4: H1.1 (p1); also elsewhere on the board
IO_SB_B5: H1.74 (p74); also elsewhere on the board
IO_SB_B6: H1.73 (p73); also elsewhere on the board
IO_SB_B7: H1.72 (p72); also elsewhere on the board
IO_SB_B8: H1.71 (p71); also elsewhere on the board
IO_WC_A0: R4.1; also elsewhere on the board
IO_WC_A1: R36.2; also elsewhere on the board
IO_WC_A2: R35.2; also elsewhere on the board
IO_WC_A3: R34.2; also elsewhere on the board
IO_WC_A4: R33.2; also elsewhere on the board
IO_WC_A5: R32.2; also elsewhere on the board
IO_WC_A6: R31.2; also elsewhere on the board
IO_WC_A7: R30.2; also elsewhere on the board
IO_WC_A8: R29.2; also elsewhere on the board
IO_WC_B0: R3.1; also elsewhere on the board
IO_WC_B1: R28.2; also elsewhere on the board
IO_WC_B2: R27.2; also elsewhere on the board
IO_WC_B3: R26.2; also elsewhere on the board
IO_WC_B4: R25.2; also elsewhere on the board
IO_WC_B5: R24.2; also elsewhere on the board
IO_WC_B6: R23.2; also elsewhere on the board
IO_WC_B7: R22.2; also elsewhere on the board
IO_WC_B8: R21.2; also elsewhere on the board
NA_VIO_2V5: HEX0.1 (CA), HEX0.6 (CA), HEX1.1 (CA), HEX1.6 (CA); also elsewhere on the board
unnamed: C3.1, PB0.2, R9.1, R11.1
unnamed: C4.1, PB1.2, R10.1, R12.1
unnamed: LED0.2 (A), R1.2
unnamed: LED1.2 (A), R2.2
unnamed: LED2.2 (A), R3.2
unnamed: LED3.2 (A), R4.2
unnamed: R5.2, SW0.2 (B)
unnamed: R6.2, SW1.2 (B)
unnamed: R7.2, SW2.2 (B)
unnamed: R8.2, SW3.2 (B)
VIO_2V5: H1.50 (p50), H1.51 (p51), H1.52 (p52), H1.53 (p53); also elsewhere on the board

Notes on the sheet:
Prototyping Pad Area
Copyright (c) 2022 Frank Migge Licensed under CERN-OHL-P v2 https://github.com/fm4dd/gm-proto-e1.git
2x push buttons with pull-up. Negative logic: press = 0.
Input: Push Buttons
4x slide switches set GND / +2V5 level signals.
Input: Slide Switches
4x 3mm LED for digital output signals.
Output: 7-Segment Display
Output: LED
2x Digits, common anode, no mulitplexing. Broadcom HDSP-7501 0.3" module

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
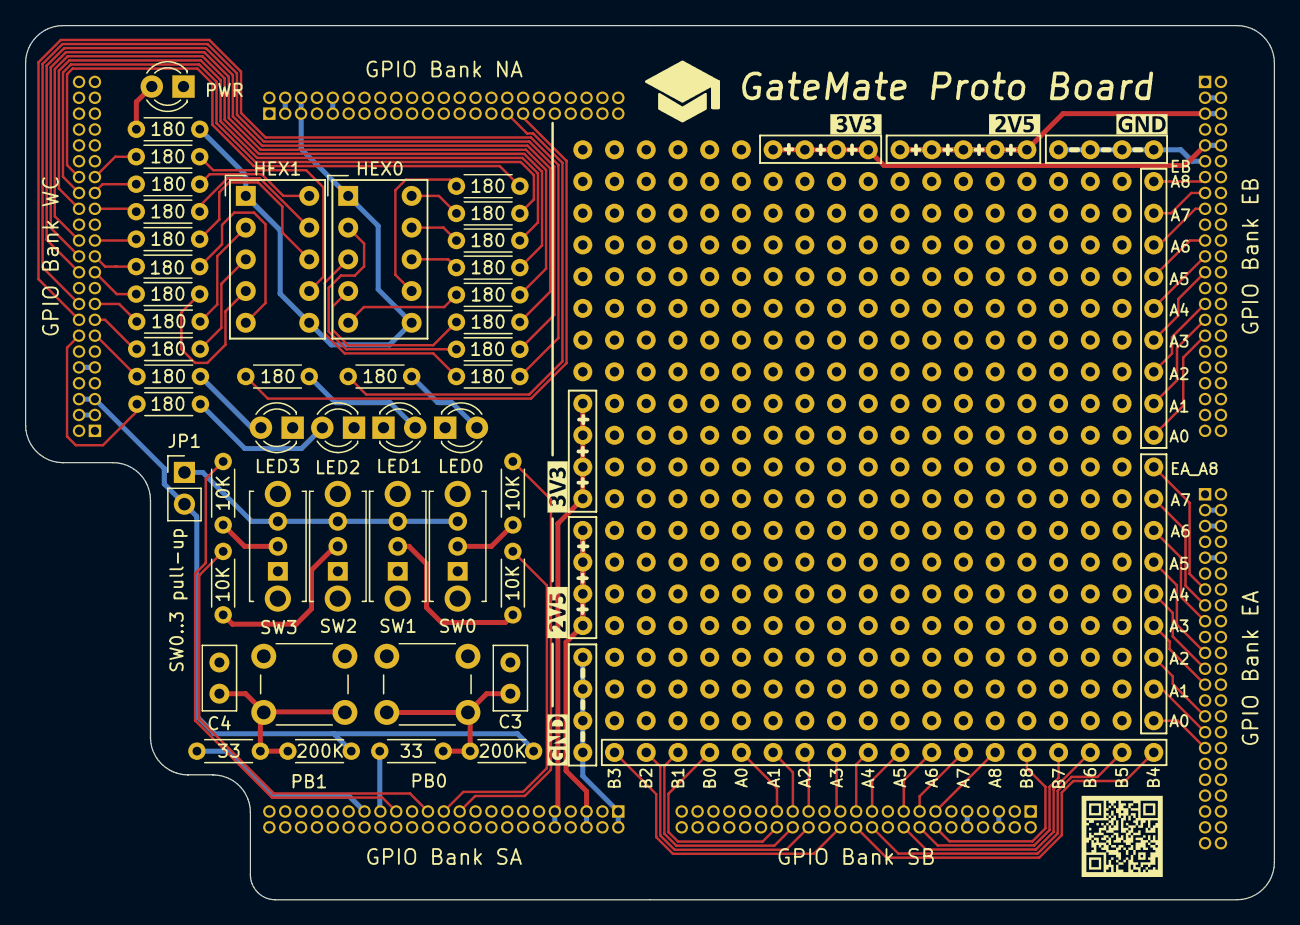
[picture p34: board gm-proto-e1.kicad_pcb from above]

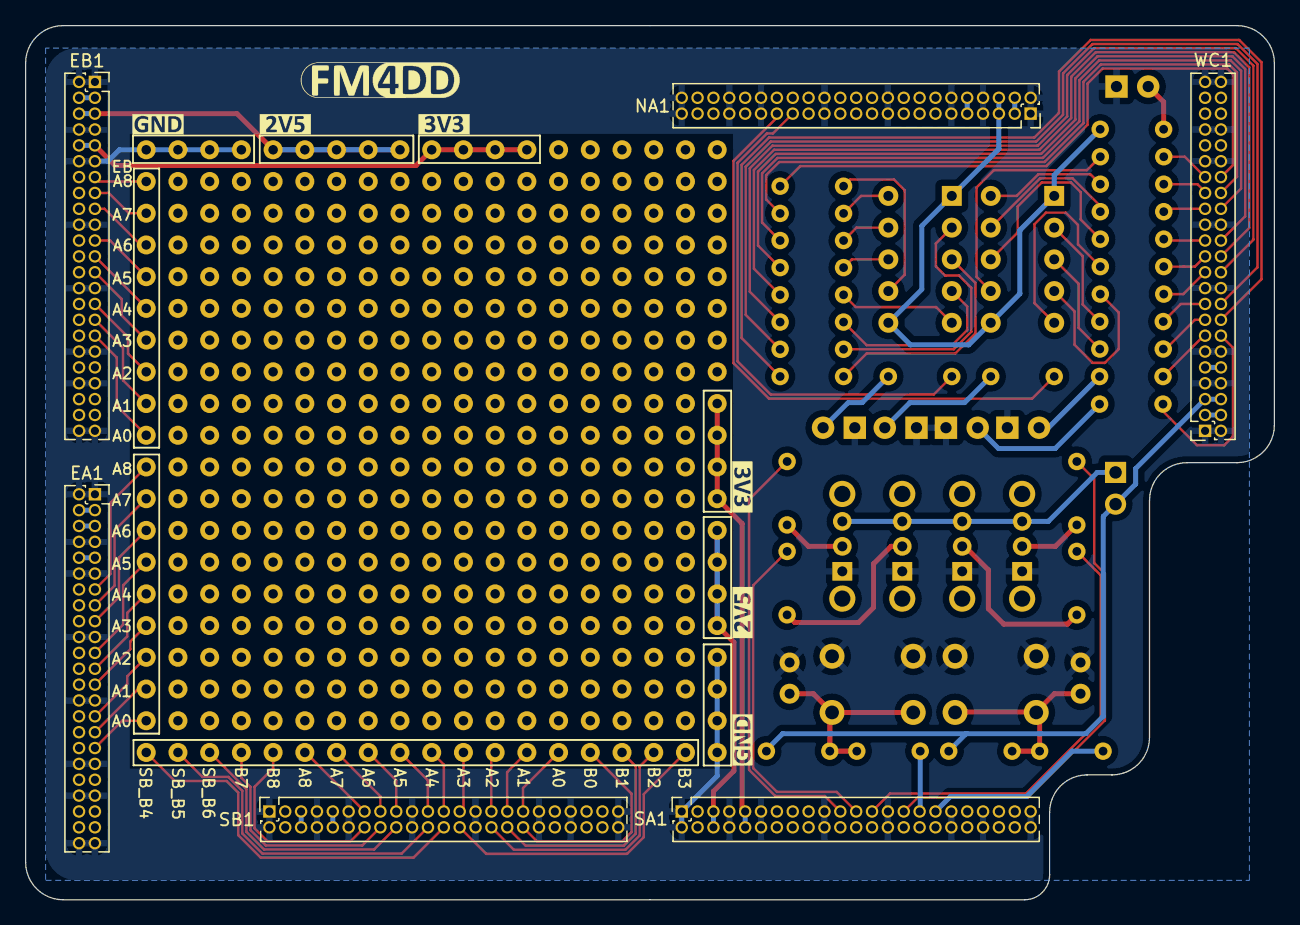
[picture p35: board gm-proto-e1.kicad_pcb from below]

Board: 2 copper layers, 100.0 x 70.0 mm, 65 parts (13 on the bottom side), 107 nets.

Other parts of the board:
LB6, LB7, LB8: Label_3V3
LB21, LB25, LB25#2: Label_2V5
LB31, LB33, LB33#2: Label_GND

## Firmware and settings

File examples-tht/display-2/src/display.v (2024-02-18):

// -------------------------------------------------------
// display.v Gatemate character LCD demo   @20240218 fm4dd
//
// Requires: character LCD installed on GM-PROTO-E1 board
//           2x7 header: 20x4 LCD 3.3V SC2004CSWB-XA-LB
//
// Description:
// ------------
// This program tests output to 20x4 character LCD display
// -------------------------------------------------------
module display(
  input clk,
  input rst, 
  input [1:0] prbtn,
  output lcd_rs,
  output lcd_en,
  output  lcd_rw,
  output [7:0] lcd_d,
  output [3:0] prled,
  output [7:0] e1led
);

// -------------------------------------------------------
// First define a pushbutton handling for display control:
// The 'PB0' button cylces between 2 states that are
// used to switch between displaying text, and sending CLS
// The pushbutton state is displayed on LEDs LED0 and LED1
// -------------------------------------------------------
parameter BTNSTATE1 = 2'b01,
          BTNSTATE2 = 2'b10;

reg [1:0] btnstate;
reg [1:0] btnnext;

initial btnstate = BTNSTATE1;
initial btnnext = BTNSTATE1;

assign e1led[7:6] = 2'b11;    // turn 2 LED off
assign prled[3:2] = 2'b00;    // turn 2 LED off
assign prled[1:0] = btnstate; // show btn0 state on LED0/1
assign lcd_rw = 1'b0;         // RW signal unused, pull-down

// -------------------------------------------------------
// Module debounce gets a clean push-button state signal
// -------------------------------------------------------
reg btn0;
wire btn0_down;
wire btn0_up;

debounce d0 (prbtn[0], clk, btn0, btn0_down, btn0_up);

always@(posedge clk) btnstate <= btnnext;

always @(*)
   case (btnstate)
      BTNSTATE1: begin
         if(btn0_down) btnnext=BTNSTATE2;
            else btnnext=BTNSTATE1;
      end
      BTNSTATE2: begin
         if(btn0_down) btnnext=BTNSTATE1;
         else btnnext=BTNSTATE2;
      end
   endcase

// -------------------------------------------------------
// End of the rst/SW3 button handling. Start LCD control:
// -------------------------------------------------------

reg [7:0] data_reg, data_next;
reg [2:0] state_reg, state_next;
reg [7:0] count_reg, count_next;
reg cd_next, cd_reg;
reg d_start_reg, d_start_next;
wire done_tick;
reg lcd_busy;

reg [5:0] lcdled;
assign e1led[5:0] = lcdled;

localparam [2:0] INIT   = 3'b000, // state machine
		 IDLE 	= 3'b001,
		 SEND	= 3'b010,
		 FIN 	= 3'b011,
		 CLS 	= 3'b100;

initial begin
   state_reg   <= INIT;
   count_reg   <= 0;
   data_reg    <= 0;
   cd_reg      <= 0;
   d_start_reg <= 0;
   lcd_busy    <= 0;
end

wire [7:0] initm[0:3];
assign initm[0] = 8'h38;  // LCD_mode 8-bit
assign initm[1] = 8'h06;  // Entry mode
assign initm[2] = 8'h0E;  // Curson on
assign initm[3] = 8'h01;  // Clear Display
 
// -------------------------------------------------------
// Set LCD display ASCII data for a 20x4 display (83 chars)
// -------------------------------------------------------
localparam charlen = 8'd83;
reg [0:charlen*8-1] line1 = { "HELLO WORLD FPGA!   ", 8'hC0,
                              "Gatemate - CharLCD  ", 8'h94,
                              "--------------------", 8'hD4,
                              "8-bit mode LCD ready" };

// -------------------------------------------------------
// Module lcd_transmit: sends a single byte to display
// -------------------------------------------------------
lcd_transmit t1(data_reg, clk, rst, d_start_reg, cd_reg, lcd_d, lcd_rs, lcd_en, done_tick);

always @(posedge clk or negedge rst)
begin
  if(!rst)
  begin
    state_reg   <= INIT;
    count_reg   <= 0;
    data_reg    <= 0;
    cd_reg      <= 0;
    d_start_reg <= 0;
    lcd_busy    <= 0;
  end
  else
  begin
    state_reg   <= state_next;
    count_reg   <= count_next;
    data_reg    <= data_next;
    cd_reg      <= cd_next;
    d_start_reg <= d_start_next;
  end
end

always @(*)
begin
  state_next = state_reg;
  count_next = count_reg;
  cd_next = cd_reg;
  d_start_next = d_start_reg;
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

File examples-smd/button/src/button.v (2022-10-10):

// -------------------------------------------------------
// button.v    gm-proto-e1 demo program    @20220924 fm4dd
//
// Requires: LEDs, Push Buttons, 7-Segment modules, clk
//
// Description:
// ------------
// This program runs a light from LED0 to LED7, or back.
// pushbutton PB0 changes the speed between 1, 2, 4, 8Hz.
// pushbutton PB1 reverses the running light direction.
// The pushbuttons are debounced, the 7-Segment modules
// show speed (HEX0: 0-3) and the direction (HEX1: F/b).
// -------------------------------------------------------
module button(
   input wire clk,
   input wire rst,
   input wire [1:0] prbtn,
   output wire [7:0] prled,
   output wire [7:0] prhex0,
   output wire [7:0] prhex1
);

// -------------------------------------------------------
//  REG/WIRE declarations
// -------------------------------------------------------
wire [4:0] data_0;
wire [4:0] data_1;
reg [7:0] lednum;
reg [22:0] div;
reg [1:0] mode;
reg speed;
reg dir;

// -------------------------------------------------------
//  Structural coding
// -------------------------------------------------------
assign prled = ~lednum;

// -------------------------------------------------------
//  Module hexdigit: Creates the LED pattern from 3 args:
// in:  0-15 displays the hex value from 0..F
//      16 = all_on
//      17 = - (show minus sign)
//      18 = _ (show underscore)
//      19 = S
//     >19 = all_off
// dp:  0 or 1, disables/enables the decimal point led
// out: bit pattern result driving the 7seg module leds
// -------------------------------------------------------
hexdigit h0 (data_0, 1'b0, prhex0);
hexdigit h1 (data_1, 1'b0, prhex1);
assign  data_0 = mode;
assign  data_1 = dir? 5'd11 : 5'd15;

// -------------------------------------------------------
// Module get_speed: Creates a clock derivate based on the
// div factor, returned into register speed.
// -------------------------------------------------------
get_speed sp (clk, rst, div, speed);

// -------------------------------------------------------
// Module debounce: get a clean push-button state signal
// -------------------------------------------------------
reg btn0, btn1;
wire btn0_down, btn1_down;
wire btn0_up, btn1_up;

debounce d0 (prbtn[0], clk, btn0, btn0_down, btn0_up);
debounce d1 (prbtn[1], clk, btn1, btn1_down, btn1_up);

always @(posedge clk or negedge rst)
begin
  if (!rst) begin
    mode <= 2'd0;
    dir <= 1'b0;
  end
  else begin
    if(btn0_down) mode = mode + 1; // increment mode
    if(btn1_down) dir = ~dir;      // change direction
  end
end

always @(posedge speed or negedge rst)
begin
  if(!rst) begin
    lednum = 8'b11111110;  // LED seed
  end
  else begin
    case (mode)
      0: div = 23'd549999;  // 8Hz
      1: div = 23'd1249999; // 4Hz
      2: div = 23'd2499999; // 2Hz
      3: div = 23'd4999999; // 1Hz
    endcase
    if(!dir)   // forward direction
      if(lednum != 8'b01111111) begin
        lednum[7] = lednum[6];
        lednum[6] = lednum[5];
        lednum[5] = lednum[4];
        lednum[4] = lednum[3];
        lednum[3] = lednum[2];
        lednum[2] = lednum[1];
        lednum[1] = lednum[0];
        lednum[0] = 1'b1;
      end
      else lednum = 8'b11111110;
    else begin  // backward direction
      if(lednum != 8'b11111110) begin
        lednum[0] = lednum[1];
        lednum[1] = lednum[2];
        lednum[2] = lednum[3];
        lednum[3] = lednum[4];
        lednum[4] = lednum[5];
        lednum[5] = lednum[6];
        lednum[6] = lednum[7];
        lednum[7] = 1'b1;
      end
      else lednum = 8'b01111111;
    end
  end
end
endmodule


// -------------------------------------------------------
// Module get_speed creates a lower frequency based on div
// -------------------------------------------------------
module get_speed(
  input wire clk,
  input wire rst,
  input reg [22:0] div,
  output reg clk_out
);

reg [22:0] count;

always @(posedge clk or negedge rst)
begin
  if (!rst) begin
    clk_out = 1'b1;
    count = 0;
  end
  else begin 
    count <= count + 1;
    if(count == div) begin
      count <= 0;
      clk_out <= ~clk_out;
    end
  end
end
endmodule

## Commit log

2022-09-18 repo init
    [data-in.kicad_sch, gm-proto-e1-dimensions.dxf, gm-proto-e1.kicad_pcb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]
2022-09-23 add SMD version
    [20220923-gm-proto-e1-smd-bom.xlsx, data-in.kicad_sch, data-io.kicad_sch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]
2022-09-24 smd schema text fixes
    [data-io.kicad_sch]
2022-09-27 assembly and tests
2022-10-16 fix blink src, add display schema
    [gm-proto-e1-charlcd.dxf]
2023-05-29 add rotary encoder
    [gm-proto-e1-charlcd.dxf]
